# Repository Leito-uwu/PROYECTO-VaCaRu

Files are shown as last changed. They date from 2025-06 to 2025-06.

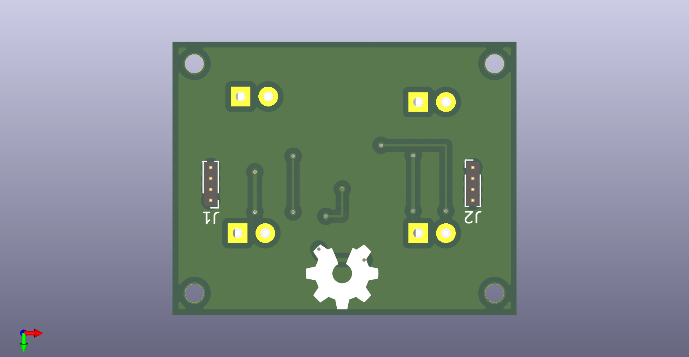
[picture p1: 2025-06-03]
01-PCB/Sensor de Color/PCBs/Sensor_TCS3200_volcado.png

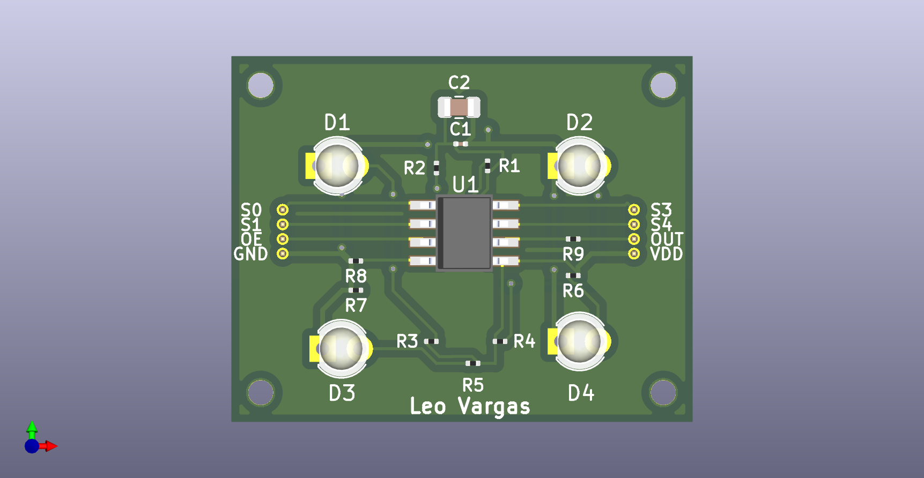
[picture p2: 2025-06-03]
01-PCB/Sensor de Color/PCBs/Sensor_TCS3200.png

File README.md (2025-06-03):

**PROTOTIPO DE SISTEMA DE CLASIFICACIÓN DE BOTELLAS DE VIDRIO AUTOMATIZADO POR COLOR**

**📝 Descripción del Proyecto**

Bienvenido a nuestro sistema de clasificación de botellas automatizado. Este proyecto está diseñado para optimizar y agilizar el proceso de separación de botellas según sus características, para esto estamos utilizando tecnología de electronica, mecánica y automatización.

Con este sistema, buscamos mejorar la eficiencia en la gestión de residuos, reducir costos operativos y promover prácticas más sostenibles en el reciclaje de envases. Nuestra solución integra sensores, procesamiento de diferenciacion de colores y algoritmos de clasificación para lograr una identificación rápida y precisa de los materiales.

¡Explora el repositorio y conoce más sobre cómo funciona este innovador sistema!

**🎯 Características Principales**

- 🔍 Clasificación Inteligente: Utiliza un sensor para identificar las caracteristicas de la botella.
- ⚡ Automatización Total: El sistema funciona de manera autónoma, reduciendo la necesidad de intervención humana.
- 🔄 Eficiencia en Procesamiento: Alta velocidad de detección y clasificación para optimizar la gestión de residuos.
- 🤖 Integración con Sensores: Emplea sensores para detectar el material y color de la botella
- 🌱 Enfoque en Sostenibilidad: Contribuye a la mejora del reciclaje y la reducción del impacto ambiental.
- 🛠️ Flexibilidad y Escalabilidad: Puede adaptarse a diferentes entornos y tipos de botellas.

**⚙️ Instalación y Configuración**

Reconfirgurable y programable, en el sentido que se puede tener acceso al codigo por ser un prototipo, y tomando en cuenta su configuracion de los sensores y actuadores. 

**🚀 Cómo Usarlo**
    Guía sobre la Funcionalidad:
    1) Colocar la botella en el comienzo de la cinta transportadora.
    2) Mediante el tablero de control, iniciar el proceso por la botonera.
    3) Detección del sensor de color e infrarrojo.
    4) Una vez detectado el brazo procede a la sujetación de la botella segun su color.
    5) Clasifica la botella en su respectivo deposito.
**🔎 Tecnologías Utilizadas**
ACTUADORES: 1 Mator Paso a Paso
            5 Servomotores
            1 Sensor FC-51
            1 Sensor TCS3200
            1 Pantalla LCD con I2C
            2 Pulsadores
            1 Driver ULN2003    
**👥 Contribución**
Autores: Alberto Ruiz
         Ramiro Caucota
         Leonardo Vargas

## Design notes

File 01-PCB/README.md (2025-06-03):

**PCB 👨‍💻**

Este apartado incluye los archivos necesarios para la fabricación y ensamblaje de la PCB del proyecto, como diseños en formato Gerber, esquemáticos, lista de materiales, archivos CAD y guías de ensamblaje de PCBs. Su objetivo es proporcionar toda la documentación requerida para replicar, modificar o mejorar el diseño original, asegurando una correcta integración del hardware con el sistema.

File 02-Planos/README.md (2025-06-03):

**PLANOS 🧑‍💻**
Este apartado contiene los planos técnicos y diagramas de la cinta transportadora, el brazo robótico y el depósito de separación, incluyendo diseños CAD, esquemáticos, lista de materiales e instrucciones de ensamblaje. Su objetivo es proporcionar la información necesaria para la fabricación y optimización de estos componentes, asegurando su correcta funcionalidad dentro del sistema.

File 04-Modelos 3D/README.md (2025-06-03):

Este apartado recopila los modelos tridimensionales de los componentes del proyecto junto con el análisis de fuerza aplicado a sus estructuras. 
Se incluyen archivos CAD detallados para impresión y ensamblaje, simulaciones que evalúan la distribución de esfuerzos y cargas en los materiales, especificaciones de los materiales utilizados y resultados de pruebas estructurales. Su objetivo es garantizar la viabilidad mecánica y optimizar el diseño, permitiendo detectar fallos, mejorar la resistencia y asegurar un desempeño óptimo en condiciones reales. Con esta información, se busca lograr un equilibrio entre eficiencia, durabilidad y seguridad en la construcción de cada elemento del sistema.

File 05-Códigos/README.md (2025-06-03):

**Codigo Fuente**
Este apartado contiene el código fuente del proyecto, estructurado en un esquema modular con carpetas separadas para maestro y esclavo. 
El código maestro gestiona la lógica central del sistema, tomando decisiones y enviando comandos a los módulos esclavos, mientras que el código esclavo ejecuta tareas específicas, como el control de motores, sensores y actuadores. Además, se incluyen protocolos de comunicación como UART, I2C para la interacción entre los dispositivos, junto con archivos de configuración para calibrar parámetros del sistema. Toda la documentación y comentarios en el código facilitan su comprensión, modificación y expansión, asegurando una implementación eficiente y adaptable a futuras mejoras.

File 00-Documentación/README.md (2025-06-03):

**DOCUMENTACIÓN 📝📓**

En este apartado se subieron la documentación  donde se explica las caracteristicas del proyecto ademas de los datasheet e informe final con todos los componentes necesarios para la comprension de la finalidad del prototipo.

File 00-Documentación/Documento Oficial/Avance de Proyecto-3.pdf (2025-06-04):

Prototipo de un Sistema Clasificador de Botellas de Vidrio en base a su color

José Ramiro Caucota

Carlos Alberto Ruiz Balderrama

Leonardo Vargas Condori

Docente: Kaleb Irahola Azad

Universidad Católica Boliviana San Pablo

Departamento de Ciencias de la Tecnología e Innovación

Carrera de Ingeniería Mecatrónica

Tarija

Prototipado Rápido

30 de mayo de 2025

Proto. De un Sis. Clasificador de botellas de vidrio en base a su color | i

TABLA DE CONTENIDO

Proto. De un Sis. Clasificador de botellas de vidrio en base a su color | ii

Proto. De un Sis. Clasificador de botellas de vidrio en base a su color | iii

LISTA DE TABLAS

Proto. De un Sis. Clasificador de botellas de vidrio en base a su color | iv

LISTA DE FIGURAS

Proto. De un Sis. Clasificador de botellas de vidrio en base a su color | v

Proto. De un Sis. Clasificador de botellas de vidrio en base a su color | vi

Proto. De un Sis. Clasificador de botellas de vidrio en base a su color | 1

RESUMEN

En Bolivia, muchas empresas de bebidas buscan reducir su impacto ambiental mediante la

reutilización de botellas de vidrio. Sin embargo, una de las principales dificultades radica en la

necesidad de separarlas por color antes de su reciclarlas. Actualmente, esta tarea se realiza de forma

manual, lo cual no solo ralentiza el proceso y resulta agotador para los trabajadores, también los

expone a riesgos por el contacto constante con el vidrio.

Ante esta problemática, el presente proyecto propone el desarrollo de un prototipo de

sistema clasificador de botellas de vidrio basado en su color, destinado a automatizar este proceso

y garantizar un manejo más seguro y eficiente. El sistema se fundamenta en sensores RGB e

Infrarrojo para identificar los colores principales de las botellas y en un mecanismo automatizado

de separación controlado mediante microcontroladores. La metodología incluyó el diseño,

construcción y prueba del prototipo en un entorno controlado.

Además, el prototipo reduce los riesgos laborales y promueve una mayor sostenibilidad

ambiental al facilitar el reciclaje de vidrio.

Palabras clave — Clasificación automática, sostenibilidad ambiental, botellas de

vidrio, Seguridad laboral, Reciclaje.

Proto. De un Sis. Clasificador de botellas de vidrio en base a su color | 2
I. PERFIL DEL PROYECTO
A. Planteamiento del problema

En Bolivia, muchas empresas de bebidas están trabajando para cuidar el medio ambiente, y

una de sus tareas más importantes es reutilizar botellas de vidrio. Pero para poder reutilizarlas

correctamente, primero hay que separarlas por color. El problema es que esto todavía se hace a

mano, con personas que pasan horas separando botellas una por una. Este trabajo no solo es lento

y cansador, sino que también puede ser peligroso, porque los trabajadores están en contacto

constante con vidrio.

Además, el método manual de clasificación presenta una alta probabilidad de errores, lo

cual repercute negativamente en la eficiencia de producción, incrementa los costos operativos y

provoca retrasos en la cadena de reciclaje. A pesar de que existen soluciones tecnológicas en otros

países, estas no resultan aplicables en el contexto boliviano debido a su elevado costo, complejidad

técnica y requerimientos de infraestructura industrial avanzada.

Por esta razón, se presenta una gran oportunidad de innovación: el desarrollo de un sistema

automatizado de clasificación de botellas por color, diseñado específicamente para el entorno

industrial nacional. Este sistema no solo optimizaría el proceso, reduciendo los errores, sino que

también mejoraría la seguridad de los trabajadores y contribuiría a la modernización de las líneas

de producción en el país.

B. Definición del problema

La clasificación manual de botellas de vidrio por color en la industria boliviana es un

proceso ineficiente, propenso a errores y riesgoso para los trabajadores. Aunque existen tecnologías

automatizadas en el mercado internacional, estas no se adaptan al contexto nacional por su alto

costo y complejidad operativa. Por tanto, se requiere una solución prototípica, automatizada y de

bajo costo, capaz de realizar esta tarea de forma segura y eficiente dentro de las limitaciones

técnicas y económicas del entorno local.

C. Objetivos
1) Objetivo General

Desarrollar un prototipo de un sistema automatizado de clasificación de botellas de vidrio

que reduzca el tiempo de clasificación respecto al proceso manual, utilizando materiales de bajo

costo, en un plazo de un mes y medio.

Proto. De un Sis. Clasificador de botellas de vidrio en base a su color | 3
2) Objetivos Específicos
- Gestionar el equipo de trabajo del proyecto con la asignación clara de roles, tareas

y herramientas de comunicación con técnicas de organización en un plazo de 2

semanas.

- Prototipar el sistema automatizado de clasificación de botellas de vidrio en un plazo

de 3 semanas, supervisando la eficiencia en el ensamblaje y asegurando un flujo de

trabajo óptimo durante todo el proceso de desarrollo.

- Evaluar el funcionamiento del prototipo en una semana, garantizando el

cumplimiento de los estándares de calidad establecidos, realizando los ajustes

necesarios para optimizar su rendimiento.

- Evaluar el rendimiento del prototipo en un plazo de una semana, con la finalidad de

verificar el cumplimiento de los estándares de calidad definidos y efectuar las

correcciones necesarias para optimizar su funcionamiento.

Delimitación

3) Límites

El presente proyecto está enfocado en el desarrollo de un prototipo funcional a escala

reducida para la clasificación automatizada de botellas de vidrio según su color. Debido a su

naturaleza académica y de prototipado rápido, se establecen las siguientes limitaciones:

- Escala reducida: No se emplearán botellas reales de vidrio. En su lugar, se utilizarán

objetos simulados fabricados en PLA u otros materiales ligeros, con dimensiones

similares a las botellas reales.

- Clasificación únicamente por color: El sistema estará diseñado exclusivamente para

diferenciar botellas según su color. No se incluirá reconocimiento de forma, tamaño,

volumen ni etiqueta.

- Componentes no industriales: Se utilizarán sensores y actuadores de bajo costo,

adecuados para demostraciones y validaciones funcionales, pero no aptos para

ambientes industriales exigentes o de alta precisión.

- Ambiente controlado: Las pruebas del sistema se realizarán en condiciones estables de

iluminación y temperatura. No se contempla el uso del prototipo en entornos con

humedad, polvo u otras variables ambientales que afecten la operación.

Proto. De un Sis. Clasificador de botellas de vidrio en base a su color | 4
4) Alcances

El alcance del proyecto contempla la diseño, construcción y validación funcional de un

sistema automatizado capaz de clasificar objetos simulados de acuerdo con su color. En este

contexto, el sistema incluirá:

- Una cinta transportadora funcional, equipada con sensores de presencia que detecten

la llegada de objetos a la zona de clasificación.

- Un sensor cromático que identifique los colores de los objetos en movimiento.
- Un brazo robótico controlado por servomotores, encargado de mover los objetos

clasificados hacia las zonas correspondientes.

- Un sistema de control embebido, basado en microcontroladores ESP32, que integre

y coordine todos los componentes del sistema.

- Una interfaz de visualización básica (pantalla LCD), para mostrar información del

estado del sistema.

Este prototipo demostrará la viabilidad técnica del proceso de clasificación automática por

color, estableciendo una base sólida para su futura adaptación a entornos industriales reales

mediante mejoras en sensores, materiales y robustez del sistema.

Proto. De un Sis. Clasificador de botellas de vidrio en base a su color | 5
II. | FUNDAMENTOS TEÓRICOS
A. Antecedentes

Se presenta el desarrollo de una estación automática de clasificación de productos basada en visión

de máquina, integrando software de código abierto y hardware comercial Allen Bradley. El

proyecto, realizado en la Universidad del Cauca, aborda el diseño mecánico median [1]te CAD

Solid Edge, la programación de visión artificial usando OpenCV en C++, y la automatización

siguiendo normas ISA. El sistema clasifica botellas plásticas y accesorios de PVC en cuatro tipos

establecidos, alcanzando una capacidad de hasta 224 botellas o 206 piezas de PVC por minuto con

un bajo margen de error del 0.8%. Se destaca la implementación de un enfoque modular y el uso

de redes industriales como DeviceNet para la comunicación entre componentes, logrando un

prototipo funcional que demuestra la viabilidad de integrar tecnologías libres y comerciales en

aplicaciones de automatización industrial. [1]

Este trabajo implementa un sistema de clasificación de botellas PET por color, utilizando visión

artificial con algoritmos de reconocimiento integrados en LabVIEW, y un sistema de control

basado en Arduino. El proceso se apoya en el algoritmo K-Nearest Neighbors (KNN) para

categorizar colores captados por una cámara, logrando una eficiencia del 75%. Se utilizó un módulo

de control neumático para realizar la separación física. Este tipo de solución se basa en técnicas de

aprendizaje supervisado y procesamiento de imágenes, fundamentales en la automatización del

reciclaje. El uso de interfaces entre software industrial y hardware embebido refuerza la viabilidad

en sistemas mecatrónicos autónomos. [2]

Se diseñó un sistema modular de banda transportadora fabricado mediante impresión 3D (material

PLA), enfocado a la emulación de procesos industriales. El proyecto se fundamenta en el uso de

sistemas de control abiertos (como Arduino), aplicando la metodología “Design Thinking” para

validar el desarrollo iterativo del prototipo. Su construcción sin tornillería permite ensamblajes

rápidos y bajos costos, y fomenta la educación técnica en el contexto de Industria 4.0. Este tipo de

prototipos representa una base didáctica y experimental ideal para pruebas de automatización,

sensores y clasificadores en procesos reales, además de ser escalables hacia aplicaciones en IoT o

monitoreo remoto. [3]

Proto. De un Sis. Clasificador de botellas de vidrio en base a su color | 6

En respuesta al aumento de residuos sólidos urbanos en Cochabamba, se diseñó un sistema

automatizado de clasificación mediante cinta transportadora y sensores. Basado en un controlador

lógico programable (PLC), el sistema identifica materiales reciclables por peso y tamaño,

dirigiéndolos a distintas áreas. Este enfoque se fundamenta en la lógica secuencial programable,

aplicada comúnmente en la industria para tareas de sorting. Al emplear sensores de proximidad,

fotointerrupción y carga, se mejora la eficiencia de clasificación y se reducen los costos operativos

y de separación manual. El sistema puede adaptarse a líneas de reciclaje urbano, mejorando la

sostenibilidad del modelo de gestión de residuos. [4]

En conclusión el desarrollo de un prototipo de sistema automatizado para la clasificación y

envasado de piezas metálicas, diseñado para optimizar los procesos industriales mediante el uso de

tecnologías neumáticas y controladores lógicos programables (PLC) con software TIA Portal V14.

El sistema incorpora cilindros neumáticos, electroválvulas, sensores magnéticos y transportadores

automatizados, permitiendo el empaquetado eficiente y seguro de productos metálicos. Entre sus

principales beneficios se destacan la reducción de costos de mano de obra, el incremento en la

seguridad de los operarios, la disminución de los tiempos de procesamiento y el aumento en la

productividad general. Este prototipo demuestra la viabilidad de la automatización como

herramienta clave para mejorar la eficiencia y la competitividad en sectores industriales como la

manufactura, automotriz, alimentario, entre otros. [5]

Proto. De un Sis. Clasificador de botellas de vidrio en base a su color | 7
III. | DISEÑO CONCEPTUAL
A. Boceto.

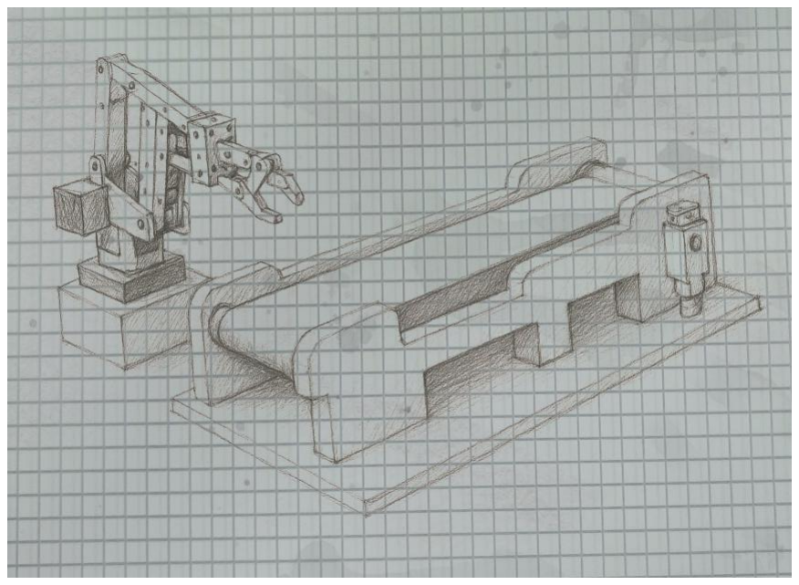
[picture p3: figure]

Figura 1 Boceto Inicial
B. Identificación de Requerimientos.

La encuesta realizada tuvo un alcance de 16 respuestas, donde los encuestados respondieron

a un total de 14 preguntas diseñadas específicamente para conocer la percepción del público

respecto al proyecto que se planea desarrollar. El objetivo principal de esta recolección de datos es

analizar las opiniones y expectativas de los usuarios potenciales, permitiendo identificar áreas de

mejora y ajustar el diseño del proyecto para asegurar su viabilidad y aceptación en el mercado.

Encuesta:

- Pregunta 1: El desarrollo del sistema representa una solución tecnológica

adecuada para el contexto local

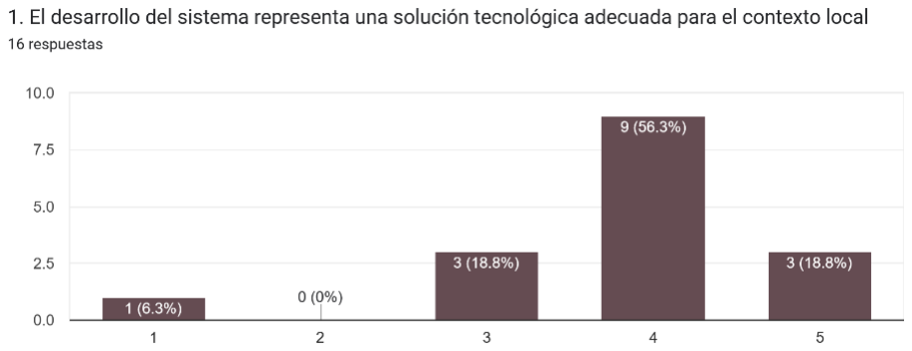
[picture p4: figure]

Figura 2 Análisis de la Pregunta 1

Proto. De un Sis. Clasificador de botellas de vidrio en base a su color | 8

El 75.1% de los encuestados considera que el sistema propuesto representa una solución

adecuada para el contexto boliviano. Esto valida la necesidad de una alternativa local, adaptada a

las limitaciones económicas y técnicas de la industria nacional.

- Pregunta 4: Que tan necesario ve que el sistema se adapte a diferentes entornos

como ser cambios en las condiciones de iluminación o humedad

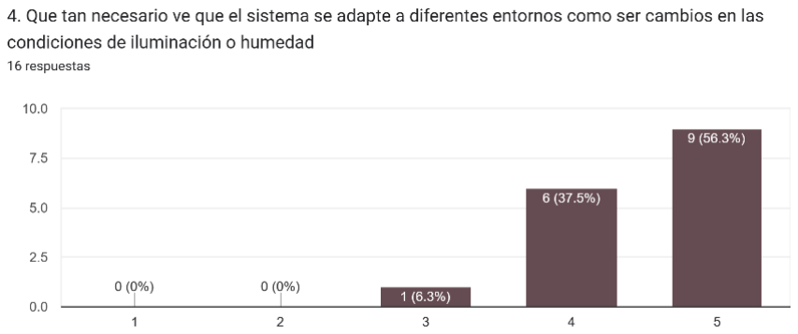
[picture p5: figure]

Figura 3 Análisis de la Pregunta 4 El 56.3% opina que el sistema debe adaptarse a condiciones variables como iluminación o

humedad. Esto plantea el requerimiento de implementar mecanismos que aseguren la robustez del

sistema ante cambios ambientales moderados.

- Pregunta 5: El prototipo debería ser fácil de operar por cualquier persona con

conocimiento básicos

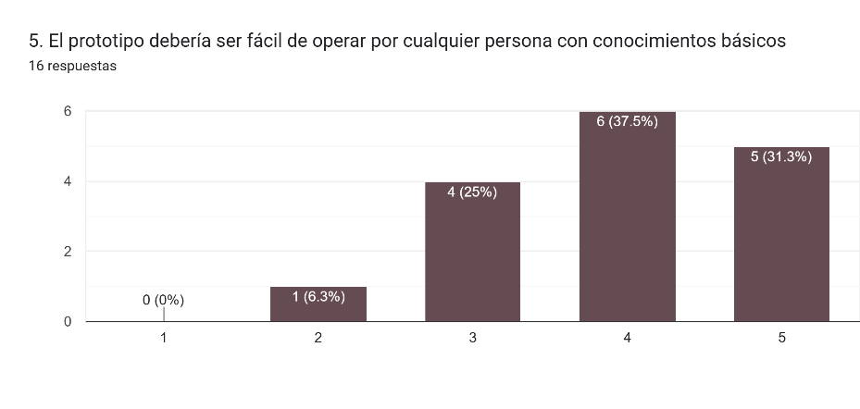
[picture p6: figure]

Figura 4 Análisis de la Pregunta 5 Donde los datos obtenidos nos muestran que un 68.8% nos indica que el prototipo del

sistema debe ser de fácil operación para las personas encargadas de manipular esta máquina, y un

25% se mantiene neutro y el 6.3% no lo ve necesario.

- Pregunta 7: EL proyecto tiene potencial para escalarse y adaptarse a distintas

necesidades de la industrial

Proto. De un Sis. Clasificador de botellas de vidrio en base a su color | 9

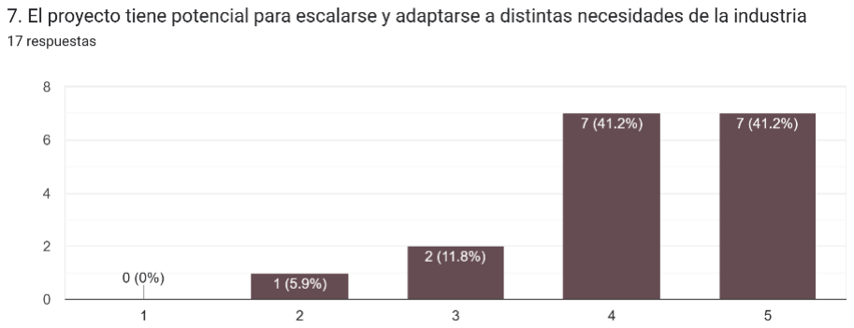
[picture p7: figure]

Figura 5 Análisis de la pregunta 7 Un 82.2% cree que el sistema puede escalarse y adaptarse a otros procesos industriales.

Esta percepción refuerza la necesidad de diseñar una arquitectura modular y flexible, con

posibilidad de integrar nuevas funciones o adaptarse a distintos flujos de trabajo, y solo un 11,8%

se mantiene neutral y el 5.9% no está de acuerdo.

- Pregunta 12: Está de acuerdo con que la automatización permitirá un flujo de

trabajo más continuo y sin interrupciones, lo que mejoraría la productividad en la

planta de reciclaje

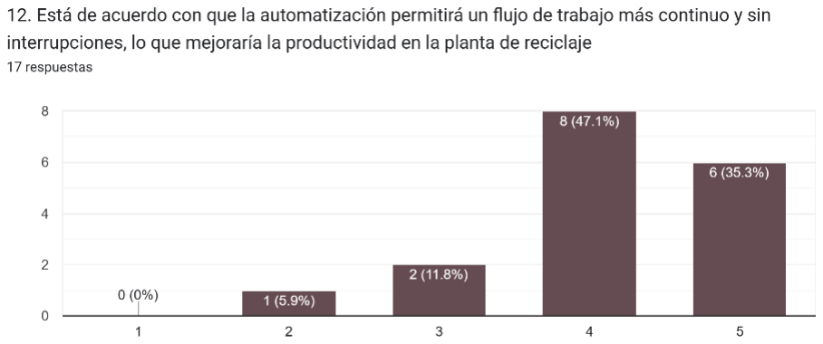
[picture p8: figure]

Figura 6 Análisis de la pregunta 12 El 82.4% considera que la automatización mejorará el flujo de trabajo en plantas

recicladoras, evidenciando el interés en reducir tiempos muertos, aumentar la eficiencia operativa

y minimizar el error humano. Y solo un 11.8% se mantiene neutro y un 5.9% no piensa está de

acuerdo.

- Pregunta 14: Considera que las empresas del sector del reciclaje de vidrio deberían

invertir en tecnologías automatizadas a pesar de los costos iniciales

Proto. De un Sis. Clasificador de botellas de vidrio en base a su color | 10

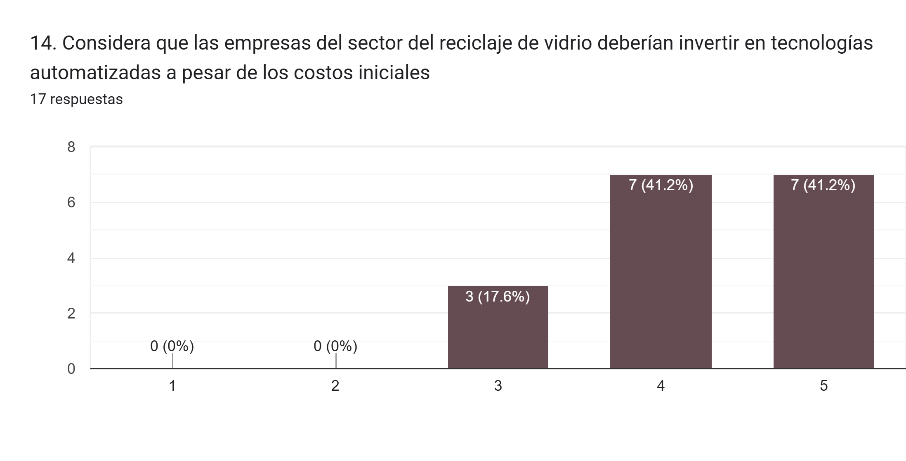
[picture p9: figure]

Figura 7 Análisis de la pregunta 14 También el 82.4% opina que las empresas del rubro deberían invertir en automatización,

incluso con un alto costo inicial, lo que sugiere que existe una disposición a adoptar nuevas

tecnologías si estas ofrecen beneficios sostenibles, luego de ello un 17.6% se mantiene neutral

respecto a esta pregunta.

C. Definición de funcionalidades.

Debe tener:

- Reconocer los colores de manera correcta: La precisión en la identificación

de colores es crucial para la correcta clasificación de las botellas.

- Sistema intuitivo para su manejo: Un sistema fácil de usar reduce el tiempo

de capacitación y minimiza errores operativos.

- Interfaz para monitoreo: La capacidad de monitorear el sistema en tiempo real

de manera remota permite detectar y corregir problemas rápidamente.

- Clasificación automática según aplicaciones específicas: La automatización

de la clasificación asegura que el proceso sea rápido y preciso.

- Materiales óptimos para el prototipo: Utilizar materiales de alta calidad

garantiza la durabilidad y fiabilidad del sistema.

- Sensores infrarrojos y ópticos: Estos sensores son esenciales para la detección

precisa de las botellas y su color.
- Área segura de trabajo para el operario: La seguridad del operario es

primordial para prevenir accidentes.

Debería tener:

Proto. De un Sis. Clasificador de botellas de vidrio en base a su color | 11
- Integrable a un proceso previamente automatizado: La capacidad de integrar

el sistema con procesos existentes facilita la implementación.

- Brazo robótico con alta precisión de movimiento: La precisión en el

movimiento del brazo robótico es crucial para la correcta manipulación de las

botellas.

- Flujo de trabajo continuo: Un flujo de trabajo sin interrupciones maximiza la

productividad.

Podría tener:

- Almacenamiento para Estadísticas. - El almacenamiento diseñado para

estadísticas implica la creación de una infraestructura que recopile, organice y

almacene grandes volúmenes de datos, permitiendo su posterior análisis.

- Aplicación Móvil para Monitero de Sistema. - Una aplicación móvil para

monitoreo de sistema permite la supervisión en tiempo real del rendimiento y

estado de un sistema o infraestructura tecnológica desde dispositivos portátiles.

- Sistema de Autodiagnóstico para Localizar Fallos. - Un sistema de

autodiagnóstico automatiza la detección y análisis de fallos dentro de una

infraestructura tecnológica o máquina. Utiliza algoritmos avanzados, como

redes neuronales o modelos de aprendizaje supervisado, para identificar

patrones de error.

- Conexión a Internet e Implementación de la Inteligencia Artificial. - La

conexión a Internet es fundamental para implementar inteligencia artificial, ya

que permite el acceso a grandes volúmenes de datos, el uso de procesamiento en

la nube y la actualización de modelos en tiempo real.

- Clasificación de más de 3 colores. - Sera esencial para la clasificación, de

objetos, tomado en cuenta rasgos de los colores principales que son: Azul, rojo

y verde, para este proceso de toma en cuenta la reflexión de luz, que nos

permitirá tener una mejor precisión al momento de aplicar el sensor.

No debe tener:

- Materiales de baja gama: Ya que no ofrecen la resistencia ni la durabilidad

necesarias para procesos de operación a largo plazo. Ocasionan fallas

Proto. De un Sis. Clasificador de botellas de vidrio en base a su color | 12

prematuras, incrementando los costos de mantenimiento y disminuyendo la

confiabilidad.

- Detección de formas o tamaños: Ya que en el proceso de reciclaje el criterio

principal de clasificación es el color de las botellas, por lo que agregar esta

funcionalidad solo aumentaría la complejidad y el costo del sistema sin aportar

un beneficio real.

- Autonomía energética: El sistema no debe operar con baterías recargables, ya

que está pensado para instalaciones industriales o semi-industriales donde se

cuenta con suministro eléctrico constante desde la red.

- Mal diseño y falta de calidad en la arquitectura: El diseño de la máquina

evitará estructuras débiles o mal ensambladas que comprometan su estabilidad.

- Fallos técnicos de manera recurrente: Minimizará fallos optimizando su

programación y asegurando una calibración precisa. Se descartarán

componentes poco fiables y se implementarán diagnósticos preventivos.

IV. DISEÑO DE INGENIERÍA

A. Selección

Para la selección de todos los puntos que requiere el proyecto se optó por el Método de

Ponderación de Criterios, donde se compararon 3 productos o métodos diferentes, de los cuales se

evaluó algunos criterios importantes para el grupo, donde se dio su respectiva ponderación, donde

se el ganador es que el obtiene el mejor puntaje.

1) Tecnologías

CRITERIO

### PONDERACIÓ

N

PRODUCTO A

PRODUCTO B
PRODUCTO C
FACILIDAD | 3 | 3 | 9 | 5 | 15 | 2 | 6
ENTORNO DE DESARROLLO | 2 | 2 | 4 | 3 | 6 | 5 | 10
COMPATABILIDAD | 4 | 2 | 8 | 5 | 20 | 3 | 12
DOCUMENTACIÓN | 1 | 3 | 3 | 4 | 4 | 3 | 3

Proto. De un Sis. Clasificador de botellas de vidrio en base a su color | 13
TOTAL | 10 | 24 | 45 | 31
Tabla 1 Tabla de decisión de Entorno de Programación En la matriz de decisión se tomaron muchos datos en cuenta como ser la facilidad de uso,

y la compatibilidad que este tiene con algunos componentes, donde son las ponderaciones más altas

y dándoles los valores necesarios se llegó a un ganador que es el Ard uino IDE con 45 puntos.

2) ComponentesCRITERIO

### PONDERACIÓ

N

PRODUCTO A

PRODUCTO B
PRODUCTO C
CONECTIVIDAD | 4 | 5 | 20 | 3 | 12 | 1 | 4
PROCESAMIENTO | 3 | 5 | 15 | 4 | 12 | 2 | 6
USO | 2 | 3 | 6 | 2 | 4 | 5 | 10
COSTOS | 1 | 4 | 4 | 3 | 3 | 4 | 4
TOTAL | 10 | | 45 | | 31 | | 24

Tabla 2 Matriz de decisión de los Microcontroladores En este apartado se comparó los microcontroladores que se usaran en el proyecto, donde

los criterios que se ponderaron con un mayor puntaje fueron los de la conectividad que estos tienen

con los diferentes componentes como ser sensores o actuadores, de igual manera su procesamiento

Proto. De un Sis. Clasificador de botellas de vidrio en base a su color | 14

que tan rápidos y eficientes son. Donde el ganador en este caso fue la ESP32 con 45 puntos seguido

de la STM32.

CRITERIO

### PONDERACIÓ

N

PRODUCTO A

PRODUCTO B
PRODUCTO C
USO | 3 | 5 | 15 | 4 | 12 | 2 | 6
COMPATIBILIDAD | 2 | 5 | 10 | 4 | 8 | 3 | 6
PRECISION | 3 | 3 | 9 | 4 | 12 | 5 | 15
COSTO | 2 | 5 | 10 | 4 | 8 | 2 | 4
TOTAL | 10 | | 44 | | 40 | | 31
Tabla 3 Matriz de decisión del Sensor de color Se compararon tres productos diferentes, donde se vio algunos criterios como ser el uso y

la precisión, ya que son puntos importantes que se necesitan para un buen desarrollo del proyecto

y una alta fiabilidad de su desarrollo. Donde el ganador fue el TCS3200, con un puntaje de 44. CRITERIO | PONDERACIÓ

N

PRODUCTO A

PRODUCTO B
PRODUCTO C
USO | 3 | 5 | 15 | 4 | 12 | 3 | 9
COMPATIBILIDAD | 2 | 5 | 10 | 5 | 10 | 4 | 8
PRECISION | 3 | 4 | 12 | 3 | 9 | 5 | 15
COSTO | 2 | 5 | 10 | 4 | 8 | 2 | 4
TOTAL | 10 | | 47 | | 39 | | 36

Tabla 4 Tabla de decisión del Sensor de Presencia

Proto. De un Sis. Clasificador de botellas de vidrio en base a su color | 15

Se buscó muchos sensores de los cuales se puso 3 los cuales se encontraban en Bolivia,

donde los criterios de evaluación fueron el uso, compatibilidad, precisión y el costo. Donde al darle

su puntaje respectivo el ganador fue FC-51 un sensor infrarrojo. CRITERIO | PONDERACIÓ

N

PRODUCTO A

PRODUCTO B
PRODUCTO C
VISUALIZACION | 3 | 5 | 15 | 3 | 9 | 4 | 12
USO | 2 | 5 | 10 | 5 | 10 | 4 | 8
COMPATIBILIDAD | 2 | 5 | 10 | 5 | 10 | 5 | 10
COSTOS | 3 | 4 | 12 | 5 | 15 | 3 | 9
TOTAL | 10 | | 47 | | 44 | | 39

Tabla 5 Matriz decisión de la Pantalla En este apartado lo que se busco fue las diferentes pantallas disponibles en el mercado,

donde las ponderaciones que se tomaron en cuenta fueron la visualización, uso, compatibilidad y

costos donde el ganador fue una pantalla LCD de 20x4, este con una ponderación de 47 puntos,

seguido de una pantalla de LCD de 16x4 con 44.

Proto. De un Sis. Clasificador de botellas de vidrio en base a su color | 16 CRITERIO | PONDERACIÓ

N

PRODUCTO A
PRODUCTO B

PRODUCTO C

PRECISION | 4 | 3 | 12 | 5 | 20 | 4 | 16
TORQUE | 3 | 3 | 9 | 5 | 15 | 4 | 12
CONTROL | 2 | 2 | 4 | 3 | 6 | 5 | 10
COMPATIBILIDAD | 1 | 4 | 4 | 5 | 5 | 5 | 5
TOTAL | 10 | | 29 | | 46 | | 43

Tabla 6 Matriz de decisión de motor Según esta matriz se compararon diferentes tipos de motores los cuales nos podrían mejorar

el desarrollo del proyecto, donde los criterios que se evaluaron fueron el de precisión y torque los

cuales fueron uno de los más importantes. Donde el ganador entre todos fue un Motor Paso a Paso

donde ganó con 46 puntos. CRITERIO

### PONDERACIÓ

N

PRODUCTO A
PRODUCTO B

PRODUCTO C

PRECISION | 3 | 5 | 15 | 3 | 9 | 5 | 15
TORQUE | 3 | 2 | 6 | 5 | 15 | 4 | 12
TAMAÑO | 2 | 5 | 10 | 2 | 4 | 5 | 10
DURABILIDAD | 2 | 3 | 6 | 4 | 8 | 5 | 10
TOTAL | 10 | | 37 | | 36 | | 47

Proto. De un Sis. Clasificador de botellas de vidrio en base a su color | 17

Tabla 7 Matriz de decisión del Servomotor En este aparatado se vieron diferentes tipos de servomotores los cuales se usarán en el brazo

robótico, donde se busca de los motores a seleccionar es la precisión y el torque esto debido que se

requiere un correcto funcionamiento del brazo. Donde dándole las puntuaciones a cada elemento

se obtuvo que el ganador fue MG90S con 47 puntos.

3) Materiales CRITERIO

### PONDERACIÓ

N

PRODUCTO A
PRODUCTO B

PRODUCTO C

FLEXIBILIDAD | 2 | 2 | 4 | 2 | 4 | 6 | 12
RESISTENCIA | 4 | 3 | 12 | 4 | 16 | 4 | 16
MANIPULABLE | 1 | 4 | 4 | 2 | 2 | 2 | 2
COSTOS | 3 | 5 | 15 | 3 | 9 | 1 | 3
TOTAL | 10 | | 35 | | 31 | | 33
Tabla 8 Matriz de decisión del Material Para la construcción de todo el proyecto se tomó en cuenta los diferentes materiales con los

que se puede imprimir, donde al comparar estos 3 productos con sus respectivos criterios se obtuvo

que el ganador fue el PLA con una puntuación de 35 puntos.

Proto. De un Sis. Clasificador de botellas de vidrio en base a su color | 18
4) Modelos

CRITERIO

### PONDERACIÓ

N

PRODUCTO A
PRODUCTO B

PRODUCTO C

PRECISION | 3 | 5 | 15 | 3 | 9 | 4 | 12
EFICIENCIA | 1 | 5 | 5 | 4 | 4 | 3 | 3
COSTOS | 2 | 4 | 8 | 5 | 10 | 3 | 6
MANTENIMIENTO | 4 | 4 | 16 | 5 | 20 | 3 | 12
TOTAL | 10 | | 44 | | 43 | | 33
Tabla 9 Matriz de decisión de la Relación de Trasmisión Para el apartado mecánico se vieron muchas opciones de como implementar los diferentes tipos

de relaciones de transmisiones, donde al evaluarlas con los siguientes criterios como ser la

precisión, el mantenimiento que se le debe dar se pudo llegar a un ganador que fue una relación

por engranajes ganadora por 44 puntos seguida de la polea con banda.

B. Esquematización
1) Diagramas de Bloques
a) Nivel 0

Proto. De un Sis. Clasificador de botellas de vidrio en base a su color | 19

Figura 8 Nivel 0 del proyecto Este nivel muestra una vista general del sistema completo. Se identifican las entradas y

salidas principales conectadas al bloque central, de igual manera se ve los servicios que se

requiere para un correcto funcionamiento del proyecto. En la parte inferior se puede ver que el

proyecto contará con una pantalla con la pueda mostrar los datos necesarios al usuario.

Este nivel resume los componentes esenciales o más básico de todo el proyecto, por eso se

define como el Nivel 0.

b) Nivel 1

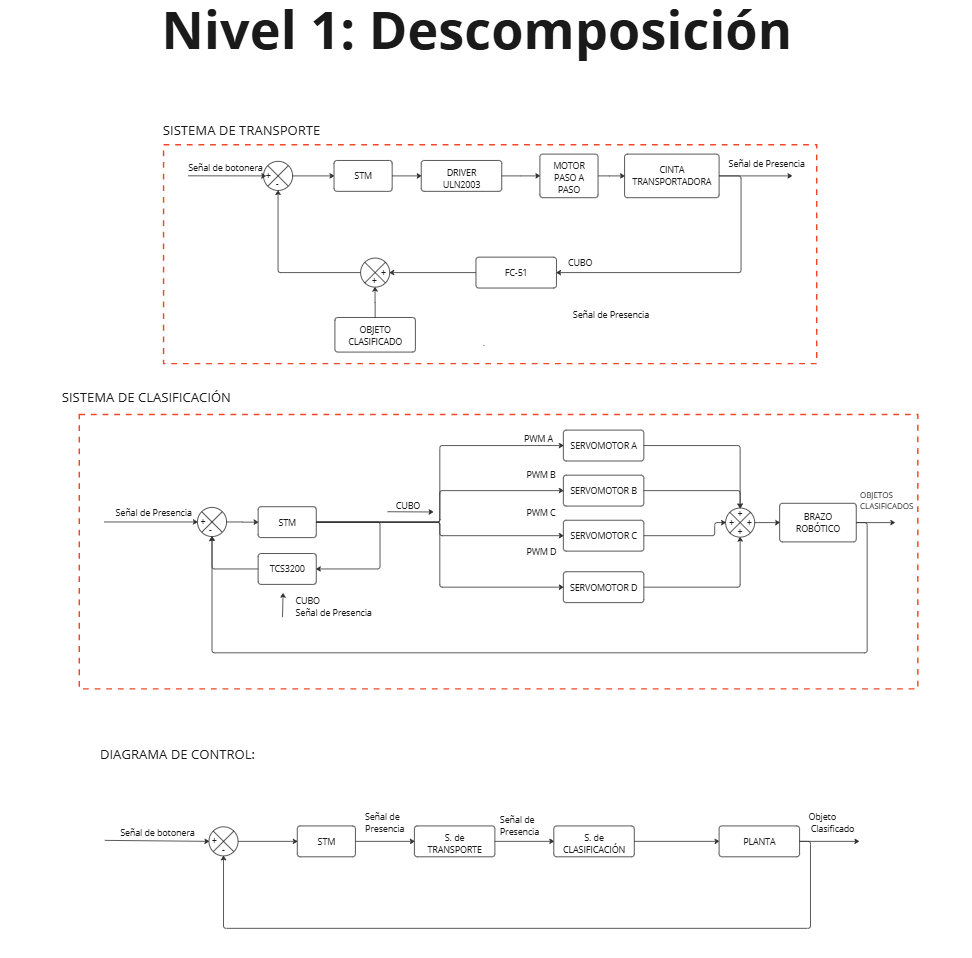
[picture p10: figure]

Figura 9 Nivel 1 del proyecto

Proto. De un Sis. Clasificador de botellas de vidrio en base a su color | 20

En este apartado se detalla cómo está construido el sistema, separándolo en tres

subsistemas, esto se hace para tener comprender de mejor manera como funciona todo el

proceso de manera genérica. Este nivel conocido como diagramas de bloques, nos muestra

cómo cada parte del sistema se comunica entre sí, siguiendo los diagramas presentes de

Control.

Como ser el subsistema de transporte el cual depende de diferentes tipos de bloques

los cuales son: el microcontrolador, que este le llega la señal de entrada la cual es comparada

con la señal retroalimentada, este toma una decisión y de eso pasa al controlador Driver

donde hace que nuestro bloque actuador que es el motor se prenda o apague, este

interactuando en nuestra planta que es la cinta transportadora, seguido de eso tenemos una

retroalimentación con nuestro sensor de FC-51, el cual debe mandar una señal al bloque

sumador, donde se debe sumar con la señal enviada por el siguiente subsistema.

En el siguiente diagrama se puede determinar como el subsistema de clasificación,

funciona con el mismo microcontrolador, el cual primero tiene una pequeña

retroalimentación con el sensor de color, el cual nos indica cual es el color del objeto. Con

esto nos manda la señal a los diferentes tipos de servomotores los cuales estarán presentes

en el brazo robótico, cada uno con un ángulo diferente, con la finalidad de llevar el objeto

a su debido lugar.

En el diagrama final se ve como ambos subsistemas están conectados en serie, donde

el microcontrolador es el encargado de mandar sus debidas órdenes a cada bloque de control

para tener una retroalimentación, viendo si el proceso se culminó.

Proto. De un Sis. Clasificador de botellas de vidrio en base a su color | 21
c) Nivel 2

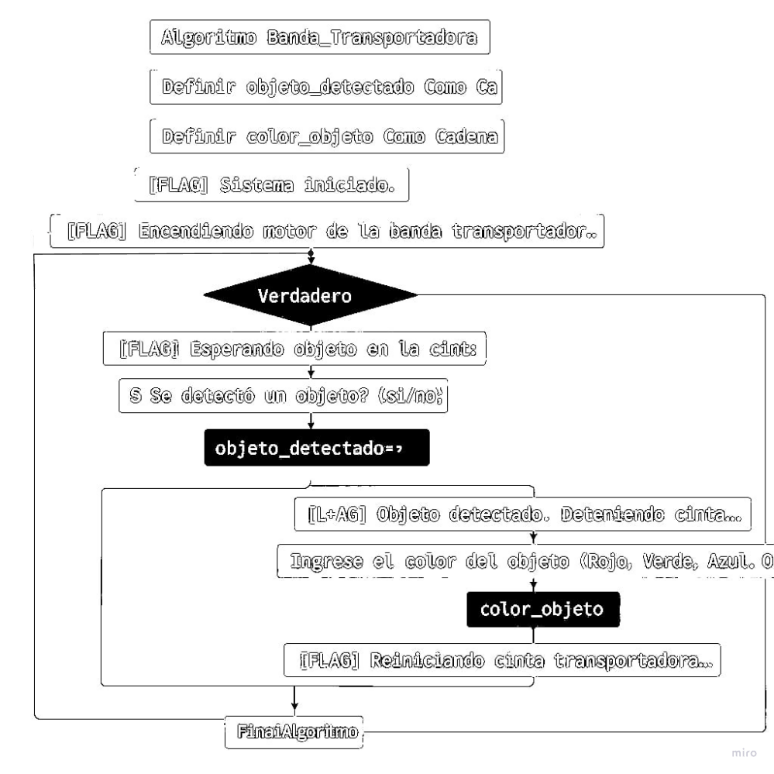
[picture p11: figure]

Figura 10 Nivel 2 de la Banda Transportadora El siguiente diagrama de flujo representa el comportamiento lógico del sistema de

clasificación por color mediante cinta transportadora. El algoritmo comienza con la activación del

motor, detecta la presencia de un objeto mediante sensor infrarrojo, y una vez detectado, se realiza

la lectura del color del objeto. Según el color identificado, el sistema procede a clasificarlo

mediante el movimiento del brazo robótico a la zona correspondiente. Finalmente, el ciclo se

reinicia.

Proto. De un Sis. Clasificador de botellas de vidrio en base a su color | 22

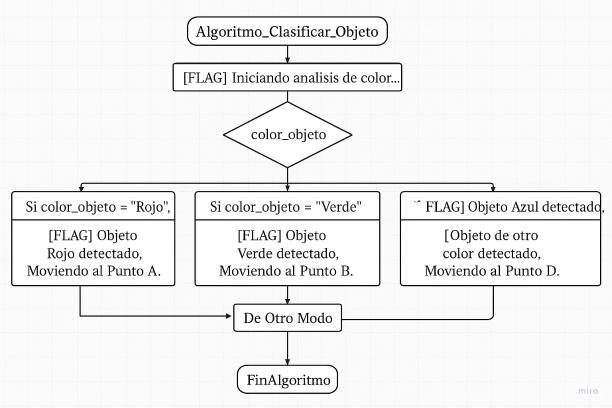
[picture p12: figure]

Figura 11 Nivel 2 del Brazo Robótico El diagrama de flujo “Algoritmo_Clasificar_Objeto” detalla la lógica interna del proceso

de clasificación según el color detectado por el sensor.

Una vez que se ha identificado un objeto y se ha leído su color, el sistema entra en esta

subrutina de decisión. Mediante una serie de condiciones, compara el valor color_objeto con los

colores programados y envía una señal al brazo robótico para mover el objeto a su posición de

destino correspondiente:

- Si el color es rojo, el objeto es enviado al Punto A.
- Si el color es verde, el objeto es enviado al Punto B.
- Si el color es azul u otro distinto, el objeto se redirige al Punto D como clasificación

general.

Proto. De un Sis. Clasificador de botellas de vidrio en base a su color | 23

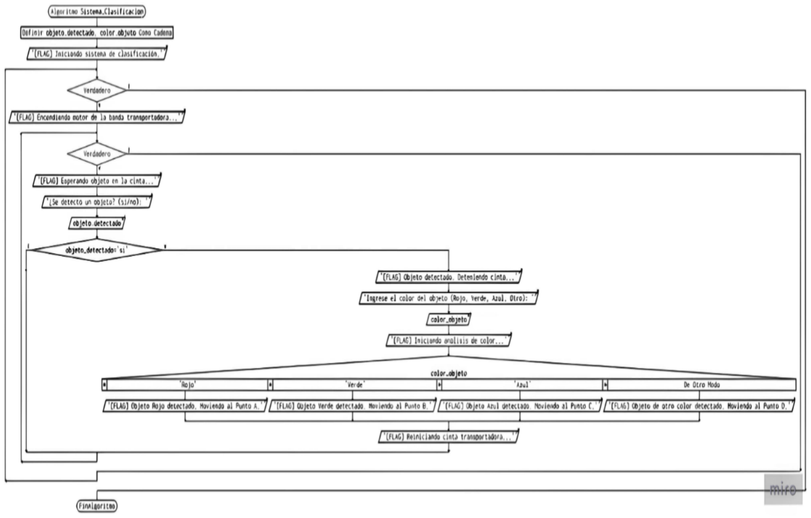
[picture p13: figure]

Figura 12 Nivel 2 de todo el proyecto El diagrama de flujo completo del sistema representa la lógica central de operación

del clasificador automático de botellas por color. Se comienza con la inicialización del

sistema, seguido del encendido del motor de la cinta transportadora. Cuando un sensor

infrarrojo detecta la presencia de un objeto, la cinta se detiene y se procede al análisis del

color utilizando un sensor cromático.

El sistema clasifica el objeto según su color, enviando señales al brazo robótico para

moverlo a un punto específico A, B, C o D. Finalmente, se reinicia la cinta y se repite el

proceso.

El Nivel 2 con diagramas de flujo muestra cómo piensa y actúa el sistema paso a paso,

dividiendo el proceso en transporte, detección, análisis de color y clasificación.

Este nivel es clave para programar el comportamiento del sistema en un microcontrolador

o software de automatización.

Proto. De un Sis. Clasificador de botellas de vidrio en base a su color | 24
d) DFP

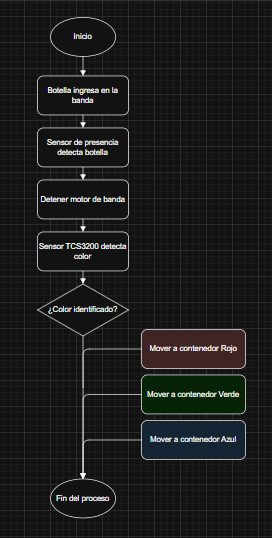
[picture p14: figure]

Figura 13 Diagrama de Flujo del Proyecto
e) Planos Mecánicos

Proto. De un Sis. Clasificador de botellas de vidrio en base a su color | 25

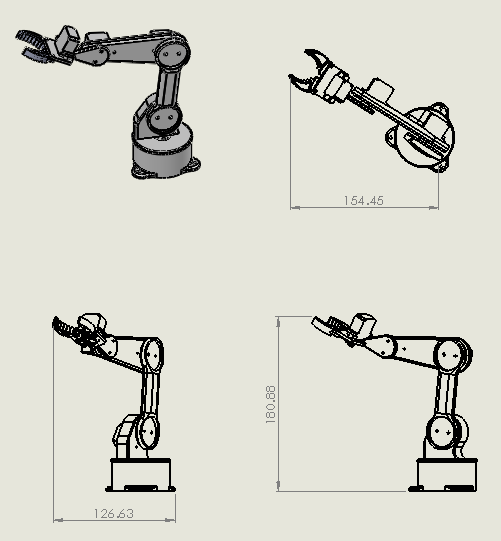
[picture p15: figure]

Figura 14 Plano Brazo Robótico

Proto. De un Sis. Clasificador de botellas de vidrio en base a su color | 26

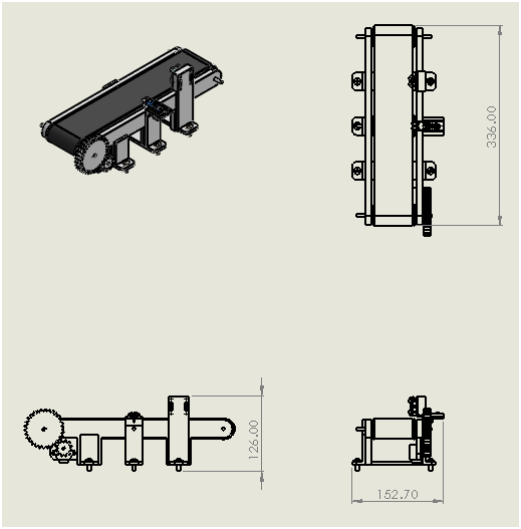
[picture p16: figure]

Figura 15 Plano Cinta Transportadora

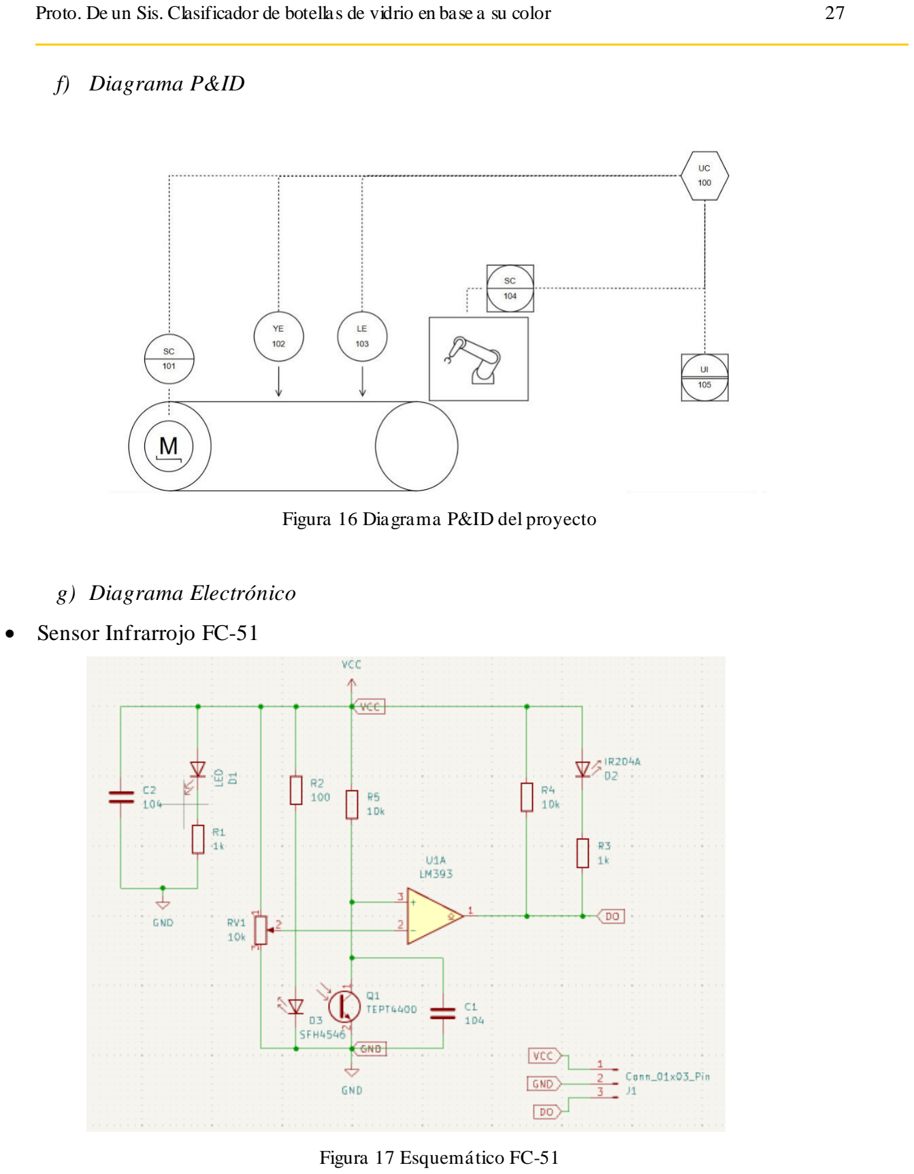
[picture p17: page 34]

Proto. De un Sis. Clasificador de botellas de vidrio en base a su color | 27
f) Diagrama P&ID

Figura 16 Diagrama P&ID del proyecto

g) Diagrama Electrónico
- Sensor Infrarrojo FC-51

Figura 17 Esquemático FC-51

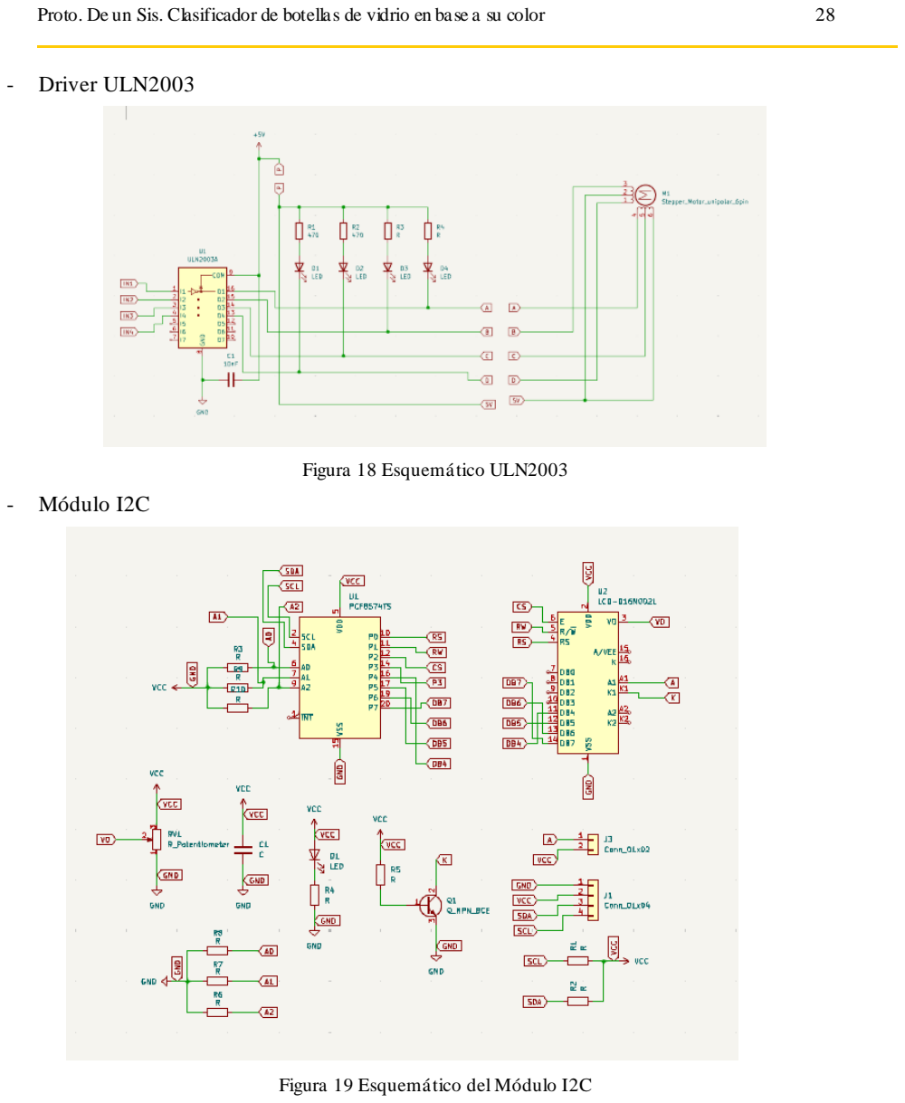
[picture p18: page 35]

Proto. De un Sis. Clasificador de botellas de vidrio en base a su color | 28
- Driver ULN2003

Figura 18 Esquemático ULN2003
- Módulo I2C

Figura 19 Esquemático del Módulo I2C

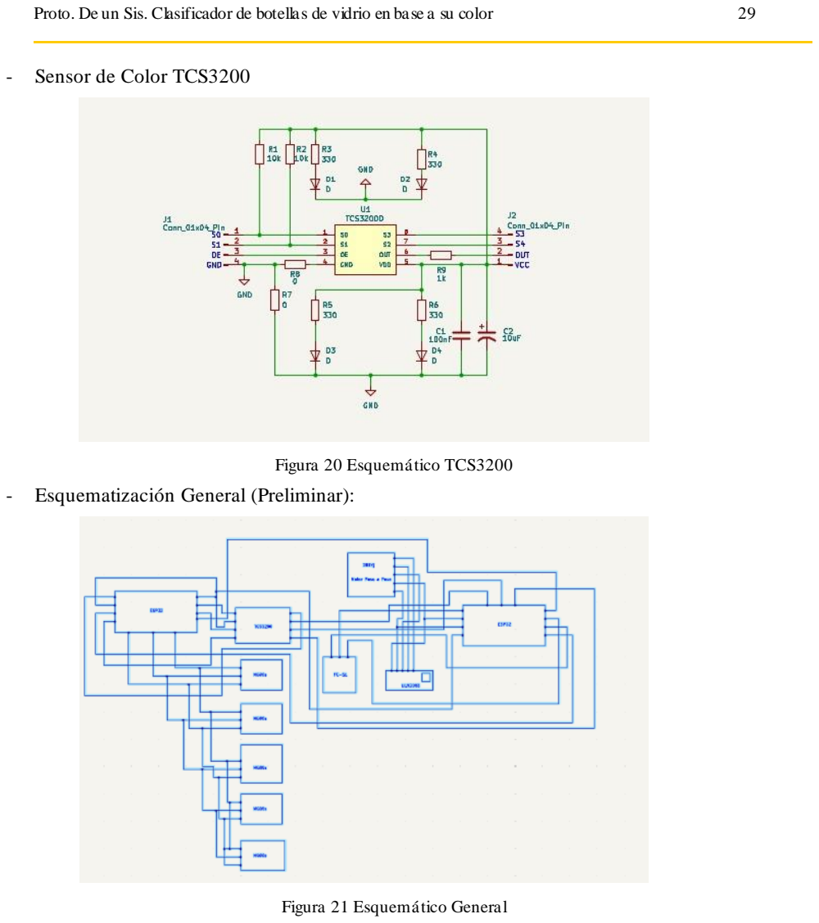
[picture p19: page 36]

Proto. De un Sis. Clasificador de botellas de vidrio en base a su color | 29
- Sensor de Color TCS3200

Figura 20 Esquemático TCS3200
- Esquematización General (Preliminar):

Figura 21 Esquemático General

Proto. De un Sis. Clasificador de botellas de vidrio en base a su color | 30
h) Diagrama PCB
- Sensor Infrarrojo FC-51

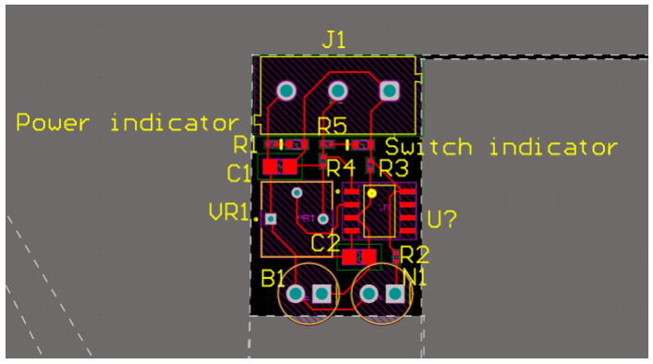
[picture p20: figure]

Figura 22 PCB FC-51
- Modulo ULN2003

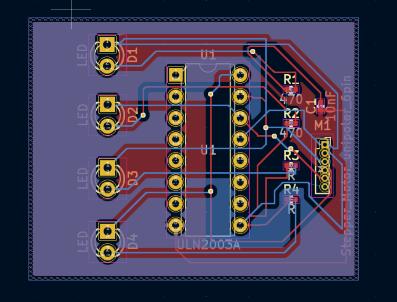
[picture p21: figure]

Figura 23 PCB ULN2003

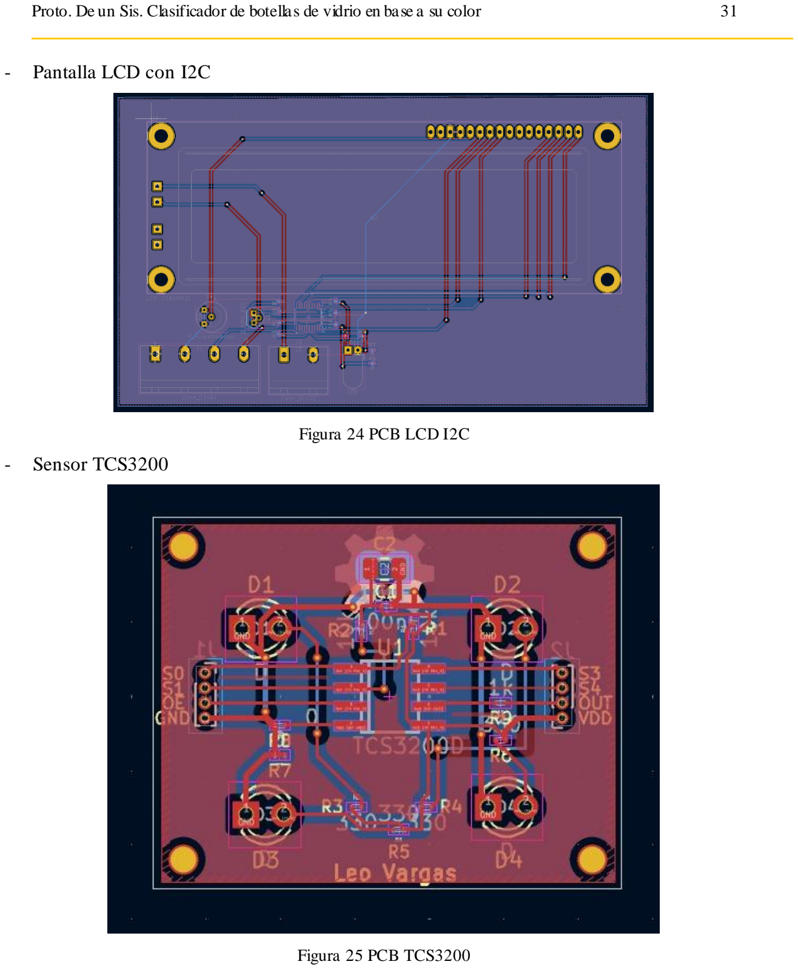
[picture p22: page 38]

Proto. De un Sis. Clasificador de botellas de vidrio en base a su color | 31
- Pantalla LCD con I2C

Figura 24 PCB LCD I2C
- Sensor TCS3200

Figura 25 PCB TCS3200

Proto. De un Sis. Clasificador de botellas de vidrio en base a su color | 32
C. Dimensionamiento
1) Estructural
a) Cálculos de Ejes

Proto. De un Sis. Clasificador de botellas de vidrio en base a su color | 33

En la parte del cálculo de fuerzas se sabe que las botellas impresas pesan alrededor de 7gr.

Donde al menos dos de ellas estarán presenten en la banda dando un peso de 14gr, sacando un

factor de estimación se busca llegó a un peso de 20gr y haciendo una conversión. Se pudo obtener

una fuerza de 0.14 N los cuales se encuentran distribuidos sobre todo el eje. Seguido de ello en las

parades de los mismos ejes se toma en cuenta el peso de estas mismas dándonos un aproximado de

0.04 N, en cada lado. Ingresando todos estos datos al MDSolid nos da los momentos flexores

máximos, donde se ingresará a la siguiente parte.

Proto. De un Sis. Clasificador de botellas de vidrio en base a su color | 34

Obtenido el Esfuerzo Normal mediante la fórmula dada, se llegó un factor de 0.509

KN/mm². Este dato se usa para saber nuestro factor de seguridad de todo el proyecto. Donde viendo

los límites a la fatiga, se llegó a un factor de seguridad de 2. Indicando que el eje si cuenta con las

especificaciones técnicas necesarias.

Proto. De un Sis. Clasificador de botellas de vidrio en base a su color | 35

En este apartado se buscó sacar el cálculo cinemático de los ejes. Donde se requiere de

varios datos los cuales ya se obtuvieron del análisis estático. Donde se puede ver que nuestro factor

de seguridad subió a 3. Indicando que el eje diseñado si cumple con los requisitos necesarios.

- Cálculos de Engranajes

Proto. De un Sis. Clasificador de botellas de vidrio en base a su color | 36

Se sabe que los engranajes tienen una relación de transmisión de acuerdo con el número

de dientes o los diámetros de las ruedas dentadas. Teniendo los dientes de 30 y 12, se llegó a una

relación de 2.5. En este caso lo que se plantea es reducir la velocidad del motor, para aumentar el

torque.

Proto. De un Sis. Clasificador de botellas de vidrio en base a su color | 37
b) Cálculos Estructurales
- Banda Transportadora
- Tensiones:

Figura 26 Análisis de tensiones
- Factor de Seguridad:

Figura 27 Análisis de Seguridad

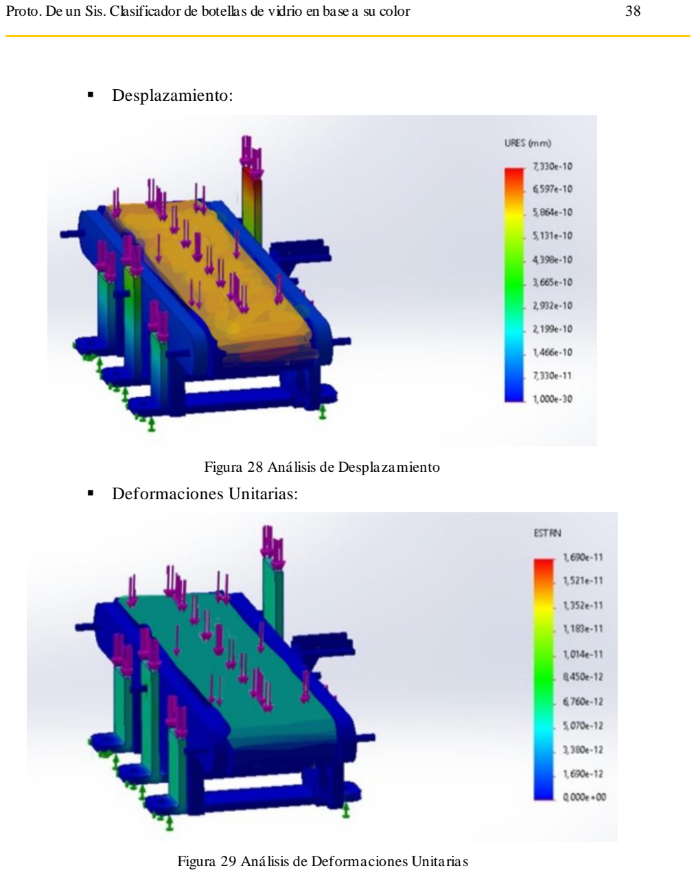
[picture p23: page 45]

Proto. De un Sis. Clasificador de botellas de vidrio en base a su color | 38
- Desplazamiento:

Figura 28 Análisis de Desplazamiento
- Deformaciones Unitarias:

Figura 29 Análisis de Deformaciones Unitarias

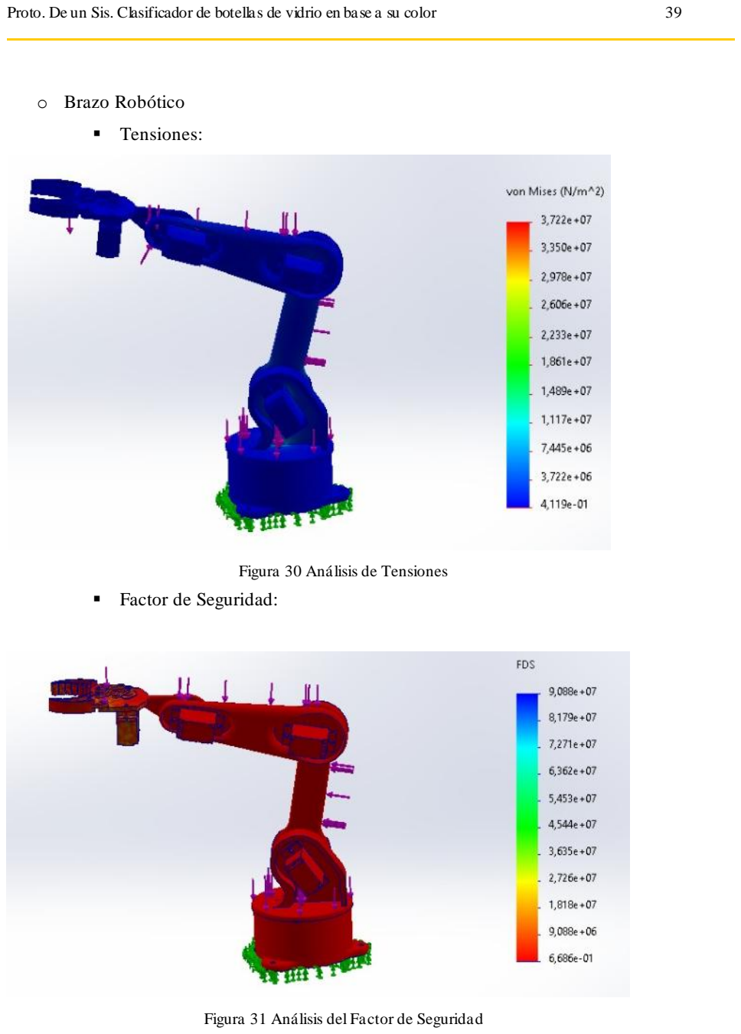
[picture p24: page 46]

Proto. De un Sis. Clasificador de botellas de vidrio en base a su color | 39
- Brazo Robótico
- Tensiones:

Figura 30 Análisis de Tensiones
- Factor de Seguridad:

Figura 31 Análisis del Factor de Seguridad

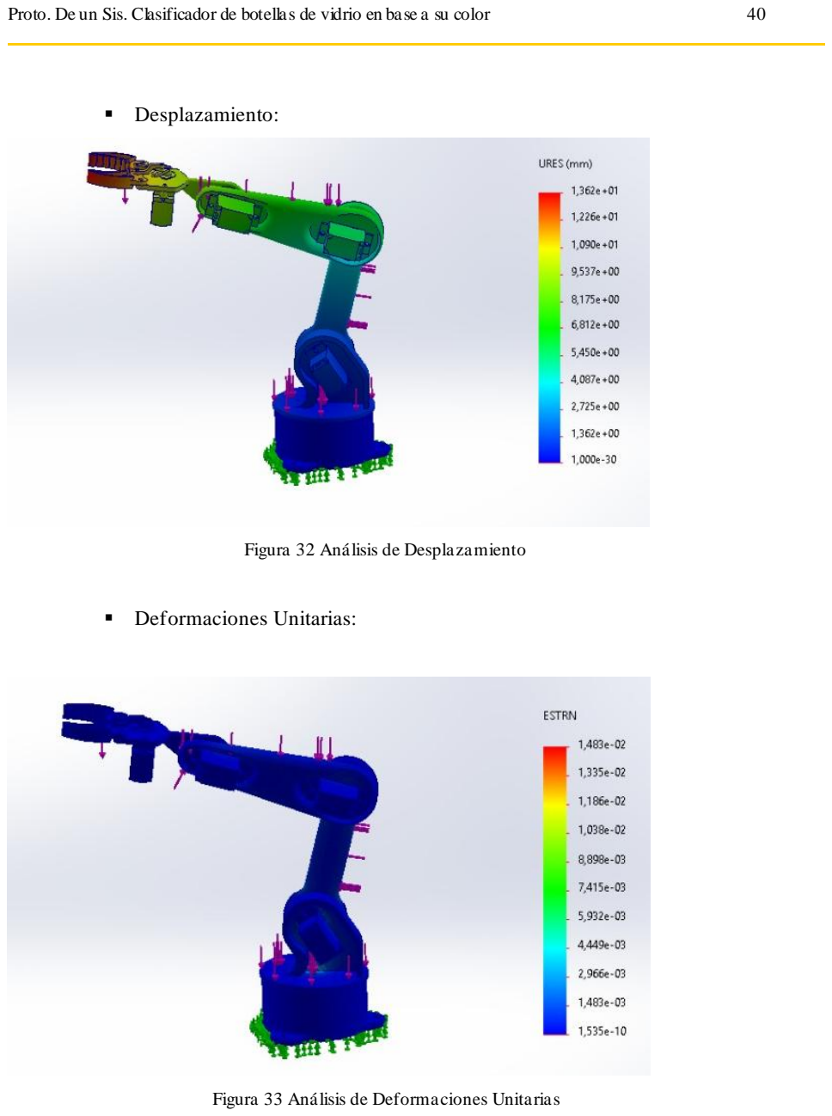
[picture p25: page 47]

Proto. De un Sis. Clasificador de botellas de vidrio en base a su color | 40
- Desplazamiento:

Figura 32 Análisis de Desplazamiento

- Deformaciones Unitarias:

Figura 33 Análisis de Deformaciones Unitarias

Proto. De un Sis. Clasificador de botellas de vidrio en base a su color | 41
2) Modelo Matemático del Brazo (Preliminar)

Proto. De un Sis. Clasificador de botellas de vidrio en base a su color | 42

Proto. De un Sis. Clasificador de botellas de vidrio en base a su color | 43

Como se mencionó al inicio, el código desarrollado en Google Colab corresponde a un

modelo preliminar del brazo robótico, el cual se encuentra en una etapa inicial de implementación.

Actualmente, se han definido las matrices de transformación homogénea para cada eslabón del

brazo, permitiendo construir tanto el modelo cinemático directo como el modelo cinemático

inverso.

Posteriormente, se aplicó la derivación correspondiente para obtener el modelo de

velocidades lineales y angulares, necesarias para el análisis dinámico futuro. Todo el desarrollo ha

sido estructurado mediante funciones reutilizables, de modo que, al ingre sar los parámetros

adecuados, se pueden obtener los resultados deseados de forma directa.

Este entorno de trabajo sienta las bases para futuras ampliaciones, como la integración de

modelos dinámicos completos, análisis de trayectorias y simulaciones más precisas del

comportamiento del sistema robótico.

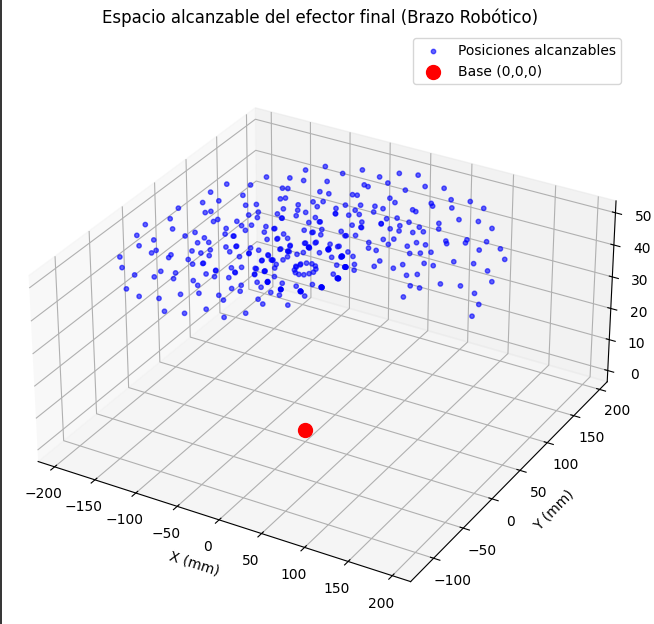
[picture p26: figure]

Figura 34 Posiciones Alcanzables del Brazo Robótico En esta gráfica se puede observar el espacio de trabajo del efector final del brazo robótico.

Debido a que el primer eslabón solo permite una rotación en un rango limitado de 0 a 180 grados,

el brazo no puede cubrir todo el entorno circular a su alrededor. Esta restricción reduce su alcance

efectivo a únicamente la mitad del área que podría cubrir si tuviera un movimiento completo de

360 grados.

Proto. De un Sis. Clasificador de botellas de vidrio en base a su color | 44

Esta limitación puede ser aceptable en aplicaciones donde el área de trabajo esté orientada

hacia un solo lado, pero debe considerarse si se desea escalar el sistema o utilizarlo en entornos

industriales más complejos.

3) Filtros

Cálculo del Filtro FIR

Un filtro FIR de orden 4 (5 coeficientes) de promedio móvil:

ℎ[k] =

1
5

, k = 0,1,2,3,4,5

Expresión general:

y[n] = ∑

1
5

∗ x[n − k]

4

k=0
Datos de Frecuencia:
- Rojo: 1200 Hz, 1220 Hz, 1195 Hz, 1210 Hz, 1205 Hz
- Verde: 1300 Hz, 1280 Hz, 1290 Hz, 1275 Hz, 1285 Hz
- Azul: 1400 Hz, 1410 Hz, 1395 Hz, 1405 Hz, 1400 Hz

Cálculo Manual:

Rojo Filtrado = 1200+1220+1195+1210+1205 5

= 1206[Hz]

Verde Filtrado = 1300+1280+1290+1275+1285 5

= 1286[Hz]

Azul Filtrado = 1400+1410+1395+1405+1400 5

= 1402[Hz]

Resultado Esperado:

- Rojo filtrado: 1206 Hz
- Verde filtrado: 1286 Hz
- Azul filtrado: 1402 Hz

Proto. De un Sis. Clasificador de botellas de vidrio en base a su color | 45
4) Prototipado

Proto. De un Sis. Clasificador de botellas de vidrio en base a su color | 46

Durante la etapa de prototipado del sistema, se utilizó impresión 3D mediante tecnología

FDM (Fabricación por Deposición Fundida), haciendo uso del software Ultimaker Cura como

entorno de configuración. Esta herramienta permitió ajustar los parámetros de impresión según las

necesidades del proyecto, priorizando la rapidez, funcionalidad y bajo consumo de recursos.

Se optó por una configuración predeterminada “Low Quality” la cual permite imprimir con

mucha más rapidez, esto resulta ideal para etapas de validación rápida. Aunque esta opción no

ofrece el mejor acabado visual, fue suficiente para piezas funcionales no estéticas, permitiendo

comprobar la geometría, el ensamblaje y la interacción entre componentes del sistema.
El material utilizado fue PLA (Ácido Poliláctico), seleccionado por su bajo costo, facilidad

de impresión y buena disponibilidad en el mercado local. Además, su rigidez es adecuada para

Proto. De un Sis. Clasificador de botellas de vidrio en base a su color | 47

prototipos que no están sometidos a esfuerzos intensos. También se valoró el hecho de que el PLA

es biodegradable, lo cual mantiene coherencia con el enfoque ambiental del proyecto.

Para las piezas que requerían soporte estructural, se eligieron soportes de tipo “árbol”, ya

que brindan estabilidad suficiente durante la impresión y, al mismo tiempo, son fáciles de remover,

reduciendo el tiempo de post-procesamiento y evitando daños en las superficies de las piezas.

También se ajustó un poco la temperatura de impresión, tanto del cabezal como de la base,

para adaptarse mejor al clima del lugar. Esto ayudó a que las piezas se pegaran bien desde el inicio

y no se deformaran mientras se imprimían.

5) Electrónico
- Cálculo de los Cables

Proto. De un Sis. Clasificador de botellas de vidrio en base a su color | 48

Para obtener los datos de los diámetros de los cables, se vio el consumo en potencia de

todos los componentes que se ubican en el proceso y con esto se obtuvo un cable con calibre de

26AWG y 22AWG.

6) PCB

Para el diseño y dimensionamiento de las pistas de la PCB se utilizaron herramientas CAD

como Altium Designer y KiCad, las cuales permitieron aplicar reglas de diseño “DRC” para definir

el ancho y separación de rutas según los requerimientos eléctricos del circuito. Se dimensionaron

las pistas considerando la corriente esperada en cada sección (alimentación, señal, tierra),

utilizando calculadoras basadas en el estándar IPC-2221. Se emplearon pistas más anchas para

líneas de alimentación y masa, y más delgadas para señales lógicas, garantizando así un diseño

seguro y funcional en una PCB de hasta dos capas.

Tabla 10 Datos estandarizados de la PCB

Proto. De un Sis. Clasificador de botellas de vidrio en base a su color | 49
7) Alimentación

### DIMENSIONAMIENTO DEL CONSUMO

Componentes | Voltaje de operación (V) | Consumo típico (mA) | Consumo máximo estimado (mA) | Cantidad | Consumo total (mA)
ESP32-S3 | 3.3 | 160 | 240 | 2 | 480
Servomotor MG90S | 4.8 – 6.0 | 200 | 300 | 5 | 1500
Motor paso a paso 28BYJ-48 | 5 | 240 | 300 | 1 | 300
Driver ULN2003 | 5 | 10 | 50 | 1 | 50
Sensor de color TCS3200 | 3.3 / 5.0 | 20 | 60 | 1 | 60
Sensor IR FC-51 | 3.3 / 5.0 | 10 | 20 | 1 | 20
TOTAL, ESTIMADO | - | - | - | - | 2410 mA (2.41 A)

Tabla 11 Cálculo de alimentación Según la tabla de estimación de consumo eléctrico, el prototipo tendrá un consumo máximo

aproximado de 2.41(A). Debido a esta demanda de corriente, no es viable alimentar el sistema

únicamente desde una fuente interna o del microcontrolador, ya que podría sobrecargarse.

Por esta razón, se requiere un sistema de alimentación externa que proporcione la energía

necesaria de forma estable y segura para todos los componentes del proyecto. Esta fuente deberá

contar con una salida de voltaje adecuada de 5V y 3.3V, y una capacidad de corriente igual o

superior al consumo máximo estimado, para garantizar el correcto funcionamiento del sistema en

todo momento.

Proto. De un Sis. Clasificador de botellas de vidrio en base a su color | 50
V. RESULTADOS
A. Resultados
- El sistema fue capaz de detectar la presencia de un objeto, identificar su color (rojo, verde

o azul) y clasificarlo automáticamente mediante el movimiento del brazo robótico hacia el

compartimiento correspondiente.

- En condiciones óptimas de iluminación, se obtuvo una precisión de clasificación del 85%,

mientras que en condiciones de baja luz, esta bajó al 70%, evidenciando la sensibilidad del

sensor al entorno lumínico.

- La estructura del prototipo se mantuvo estable durante el funcionamiento, gracias al uso de

materiales adecuados y un diseño mecánico correcto.

- El brazo robótico cumplió con las trayectorias planificadas, aunque se observó una

limitación en el alcance angular, ya que el movimiento de la base solo cubre un rango de 0

a 180°, restringiendo el área de trabajo del efector final.

- Durante la fase de pruebas, se identificaron algunos inconvenientes menores relacionados

con la calibración del sensor de color y el control del servomotor. Sin embargo, estos fueron

corregidos rápidamente aplicando el filtrado de señales. El sistema demostró un desempeño

aceptable, cumpliendo con los estándares básicos definidos al inicio del proyecto (detección

y separación de botellas por color).

- Se realizaron pruebas de estrés del sistema, evaluando la precisión en la clasificación de

botellas en distintas condiciones de iluminación y velocidad de la cinta. El rendimiento

alcanzó una efectividad del 85% en condiciones óptimas y del 70% en condicio nes de

iluminación baja, lo cual permitió hacer ajustes en el posicionamiento del sensor.

B. Conclusiones
- Se comprobó que la automatización del proceso de clasificación no solo reduce el tiempo

requerido por operador, sino que también disminuye el riesgo de accidentes laborales, lo

cual contribuye a un entorno de trabajo más seguro.

- Se concluyó que las aplicaciones de simulaciones ayudan mucho al desarrollo del proyecto,

esto viendo, previniendo errores a futuro, y al mismo tiempo modelando las piezas para

poder construirlas al final.

Proto. De un Sis. Clasificador de botellas de vidrio en base a su color | 51
- A pesar del éxito del prototipo, se identificaron áreas de mejora importantes, especialmente

en la estabilidad del reconocimiento de color y la ampliación del rango de trabajo del brazo.

C. Recomendaciones
- Si bien el sensor TCS3200 cumple su función, su precisión se ve afectada en condiciones

de baja iluminación. Se recomienda implementar un sistema de calibración automática o

utilizar sensores más avanzados con filtros integrados para mejorar la exactitud d el

reconocimiento cromático.

- El sistema debería contar con protección ante factores externos como humedad, polvo o

vibraciones. Para esto, se sugiere diseñar una carcasa protectora o encapsular los sensores

más delicados.

- Diseñar una carcasa protectora para los componentes electrónicos, especialmente sensores

y microcontroladores, con el fin de evitar fallas por humedad, polvo o impactos.

- Incorporar una memoria SD o conexión a una base de datos permitiría registrar el número

de botellas clasificadas por tipo, errores detectados y eficiencia general. Esta información

sería útil para análisis posteriores o validación industrial.

Proto. De un Sis. Clasificador de botellas de vidrio en base a su color | 52
VI. | REFERENCIAS
[1] O. D. Valzco, Diseño y Construccion de Estacion de Clasificacion Autoamtica,

Casuca - Colombia: Machine Vision, 2013.

[2] M. F. M. Pérez, Etapa de identificación y clasificación de botellas de PET, en

máquina prototipo separador de botellas, Mexico, 2020 .

[3] L. A. L. López, Sistema mecatrónico de banda transportadora usando impresión

3D para la emulación de procesos industriales, Colombia-Cali, 2022.

[4] | N. | N. | J. | ISMAEL, | AUTOMATIZACIÓN | DE | UNA | CINTA

TRANSPORTADORA PARA LA SEPARACION DE RESIDUOS RECICLABES SEGUN PESO O TAMAÑO, BOLIVIA - Cochabamba, 2024.

Proto. De un Sis. Clasificador de botellas de vidrio en base a su color | a

ANEXOS

Miro

https://miro.com/welcomeonboard/d0VZcmZudFMzZWpQcWEzdktvRURLLyt3S0JqNm

h0eW42eG4rVFZpNjY4WE45VXlob2RSbkg0ZnJvMUZ0WkZwZ1l1a0p6cnJ4ZUxXSEQzOUc

yZ0hEZEpRdkh0ZFRiOXVka1VaZ0I4dDF0Zm1ydXA1WXZ1WS92SnQ2WW1uN2k1aTBnbH

pza3F6REdEcmNpNEFOMmJXWXBBPT0hdjE=?share_link_id=140537677327 (https://miro.com/welcomeonboard/d0VZcmZudFMzZWpQcWEzdktvRURLLyt3S0JqNmh0eW42eG4rVFZpNjY4WE45VXlob2RSbkg0ZnJvMUZ0WkZwZ1l1a0p6cnJ4ZUxXSEQzOUcyZ0hEZEpRdkh0ZFRiOX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)

Formulario

https://forms.gle/agBcHq2ziUJrA7fN7

Drive

https://drive.google.com/drive/folders/1f7mmO3LOPDSBSi_uL6BorWe6adDavS6_?usp

=sharing (https://drive.google.com/drive/folders/1f7mmO3LOPDSBSi_uL6BorWe6adDavS6_?usp=sharing)

Excel

Avances de Proyecto.xlsx

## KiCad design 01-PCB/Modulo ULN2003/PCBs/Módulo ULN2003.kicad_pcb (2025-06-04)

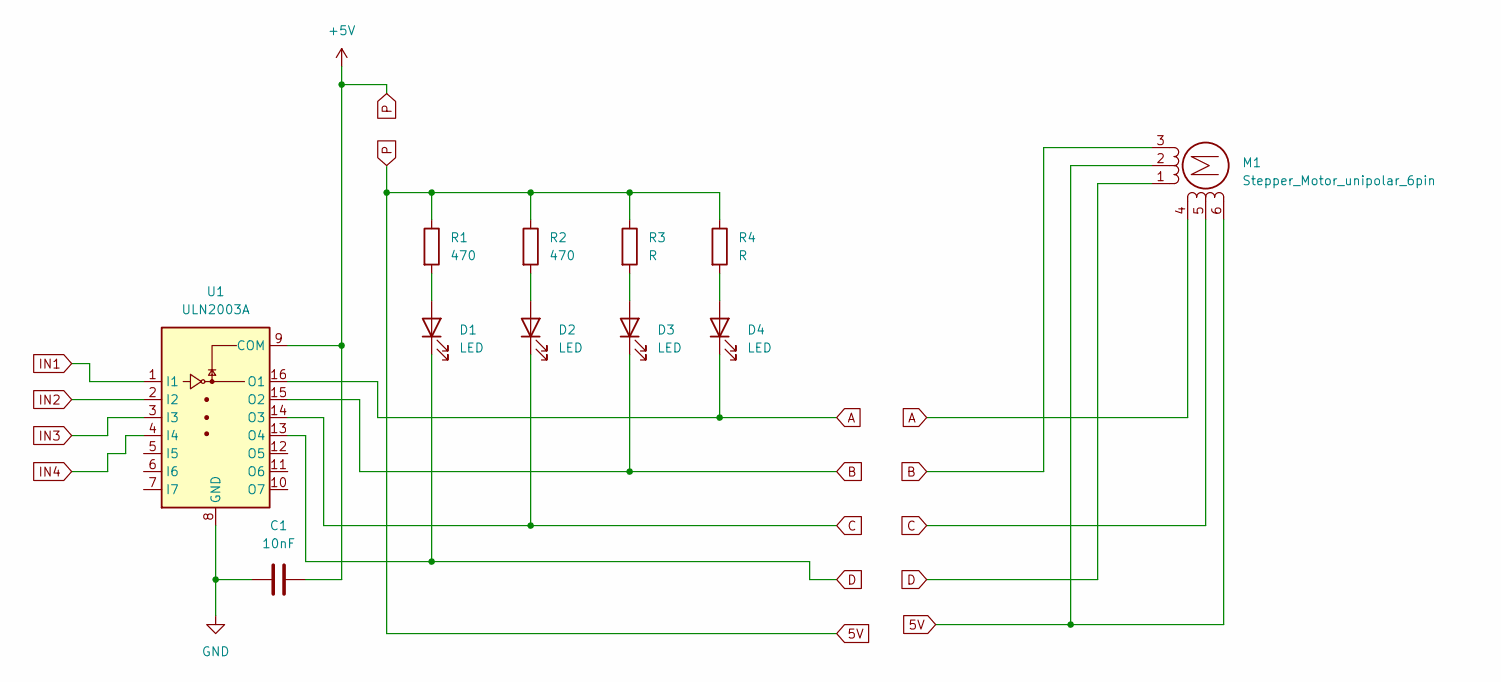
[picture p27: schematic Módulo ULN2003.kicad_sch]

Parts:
C1: 10nF; C_0402_1005Metric
D1, D2, D3, D4: LED; LED_D3.0mm
M1: Stepper_Motor_unipolar_6pin; PinSocket_1x06_P1.00mm_Vertical
R1, R2: 470; R_0402_1005Metric
R3, R4: R; R_0402_1005Metric
U1: ULN2003A; DIP-16_W7.62mm

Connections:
5V: C1.2, M1.2, M1.6, R1.1, R2.1, R3.1, R4.1, U1.9 (COM)
A: D4.1 (K), M1.4, U1.16 (O1)
B: D3.1 (K), M1.3 (-), U1.15 (O2)
C: D2.1 (K), M1.5, U1.14 (O3)
D: D1.1 (K), M1.1, U1.13 (O4)
GND: C1.1, U1.8 (GND)
IN1: U1.1 (I1)
IN2: U1.2 (I2)
IN3: U1.3 (I3)
IN4: U1.4 (I4)
unnamed: D1.2 (A), R1.2
unnamed: D2.2 (A), R2.2
unnamed: D3.2 (A), R3.2
unnamed: D4.2 (A), R4.2

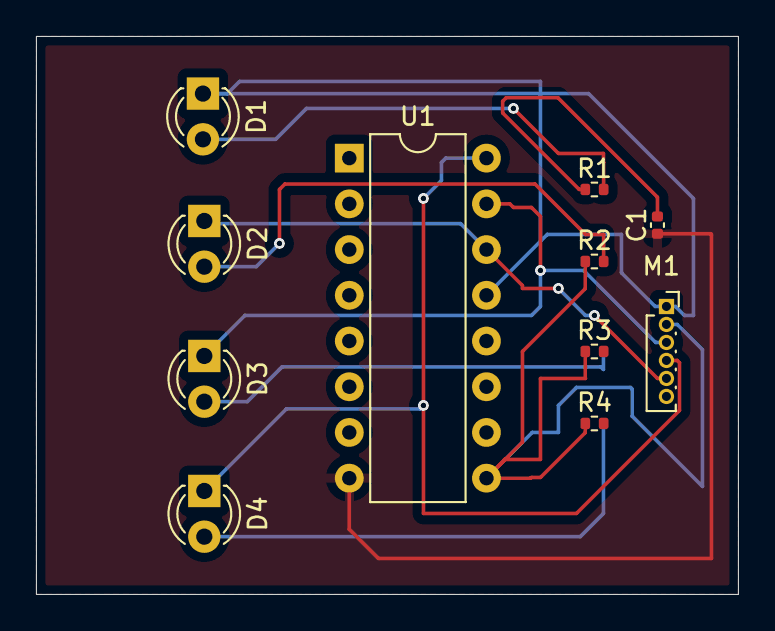
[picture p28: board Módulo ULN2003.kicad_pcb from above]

Board: 2 copper layers, 39.0 x 31.0 mm, 11 parts (0 on the bottom side), 10 nets.

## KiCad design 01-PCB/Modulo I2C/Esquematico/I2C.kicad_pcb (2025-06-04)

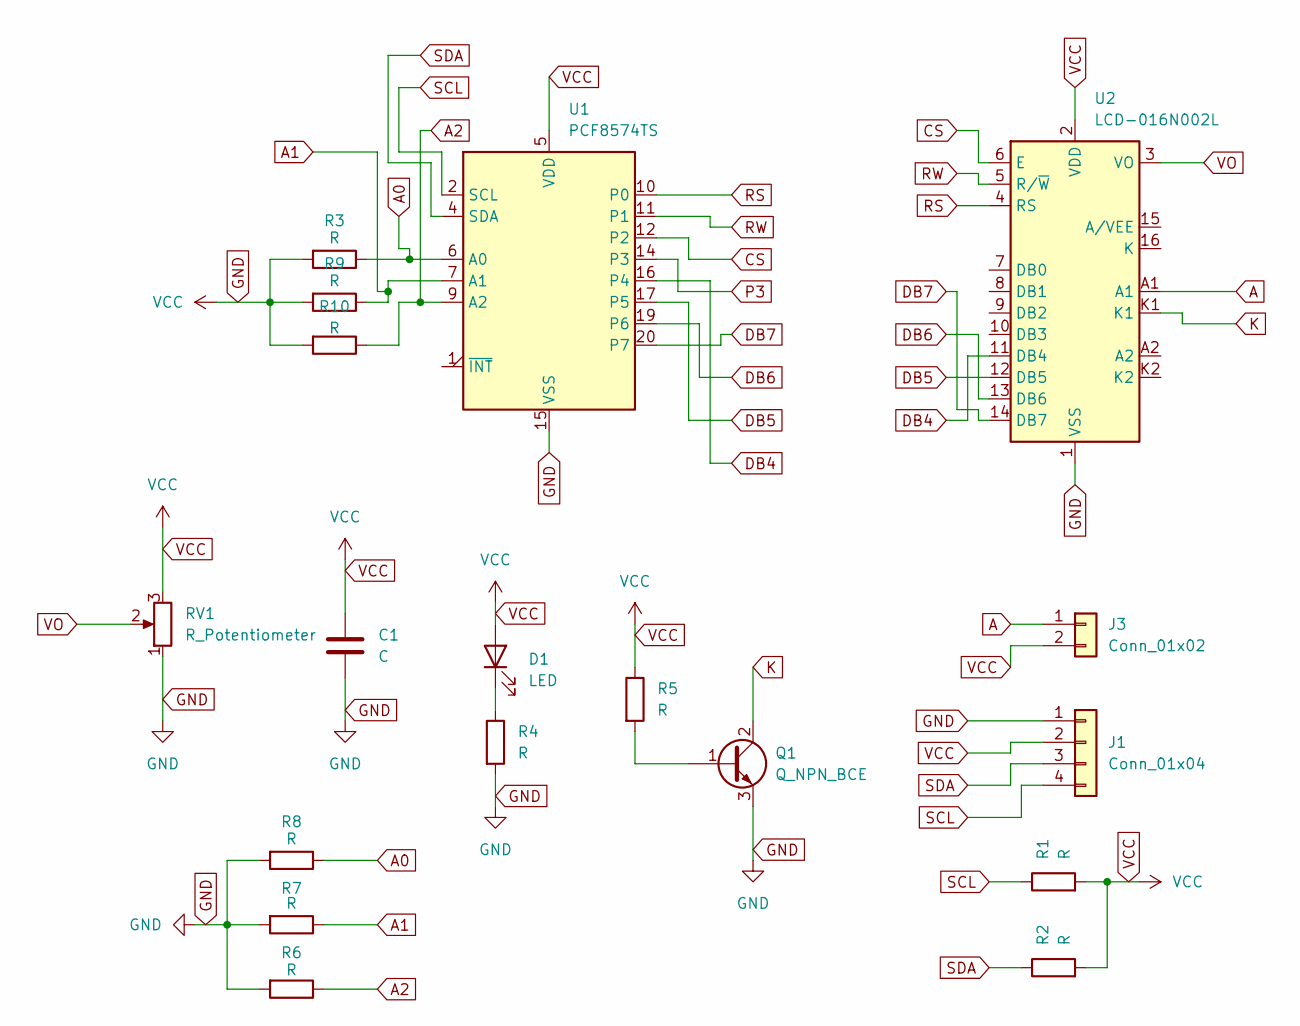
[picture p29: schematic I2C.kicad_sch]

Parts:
C1: C; C_0402_1005Metric
D1: LED; LED_D5.0mm_Horizontal_O1.27mm_Z3.0mm
J1: Conn_01x04; PhoenixContact_GMSTBA_2,5_4-G-7,62_1x04_P7.62mm_Horizontal
J3: Conn_01x02; PhoenixContact_GMSTBA_2,5_2-G_1x02_P7.50mm_Horizontal
Q1: Q_NPN_BCE; TO-92
R1, R2, R3, R4, R5, R6, R7, R8, R9, R10: R; R_0402_1005Metric
RV1: R_Potentiometer; Potentiometer_Bourns_3339H_Vertical
U1: PCF8574TS; SSOP-20_4.4x6.5mm_P0.65mm
U2: LCD-016N002L

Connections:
A: J3.1, U2.A1
A0: R3.1, R8.1, U1.6 (A0)
A1: R7.1, R9.1, U1.7 (A1)
A2: R6.1, R10.1, U1.9 (A2)
CS: U1.12 (P2), U2.6 (E)
DB4: U1.16 (P4), U2.11 (DB4)
DB5: U1.17 (P5), U2.12 (DB5)
DB6: U1.19 (P6), U2.13 (DB6)
DB7: U1.20 (P7), U2.14 (DB7)
GND: C1.1, C1.2, D1.2 (A), J1.1, J1.2, J3.2, Q1.3 (E), R1.2, R2.2, R3.2, R4.2, R5.1, R6.2, R7.2, R8.2, R9.2, R10.2, RV1.1, RV1.3, U1.5 (VDD), U1.15 (VSS), U2.1 (VSS), U2.2 (VDD)
K: Q1.2 (C), U2.K1
unnamed: D1.1 (K), R4.1
unnamed: Q1.1 (B), R5.2
P3: U1.14 (P3)
RS: U1.10 (P0), U2.4 (RS)
RW: U1.11 (P1), U2.5 (R/~W)
SCL: J1.4, R1.1, U1.2 (SCL)
SDA: J1.3, R2.1, U1.4 (SDA)
VO: RV1.2, U2.3 (VO)

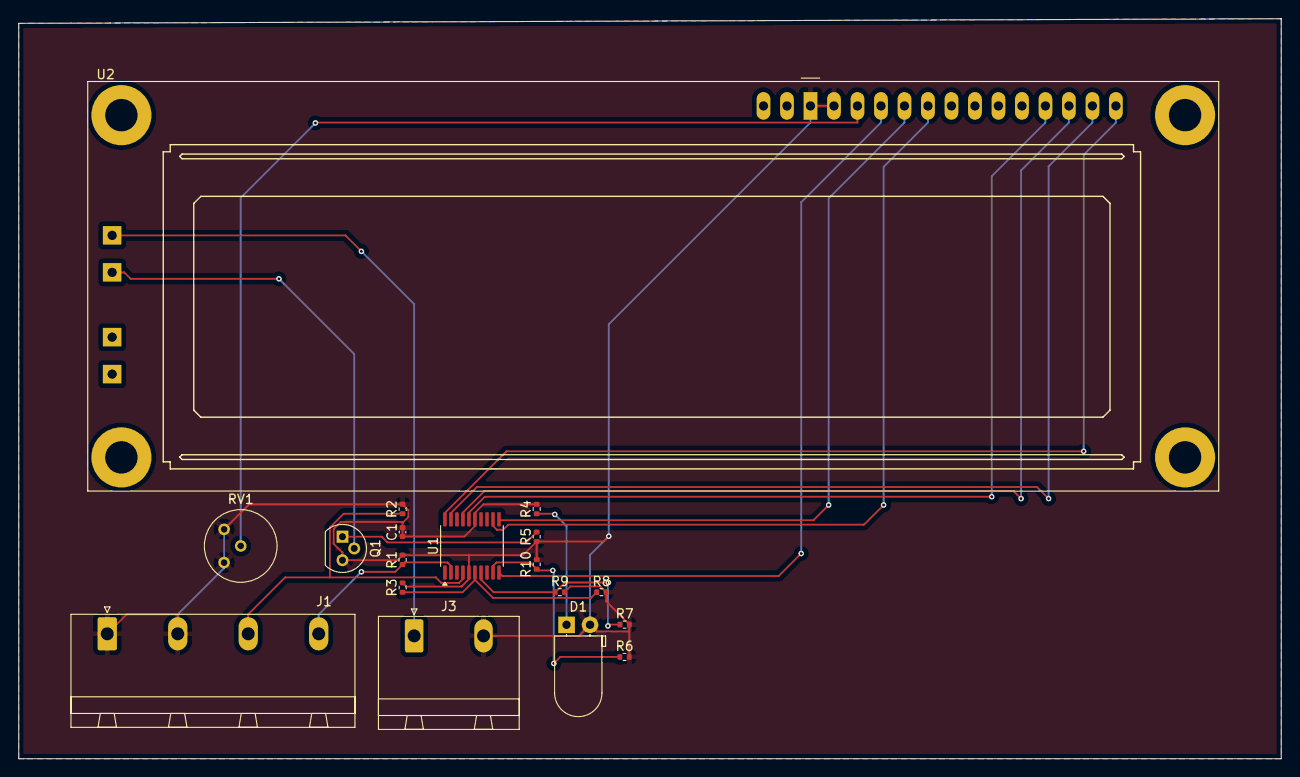
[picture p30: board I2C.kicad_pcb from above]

Board: 2 copper layers, 136.5 x 80.0 mm, 18 parts (0 on the bottom side), 18 nets.

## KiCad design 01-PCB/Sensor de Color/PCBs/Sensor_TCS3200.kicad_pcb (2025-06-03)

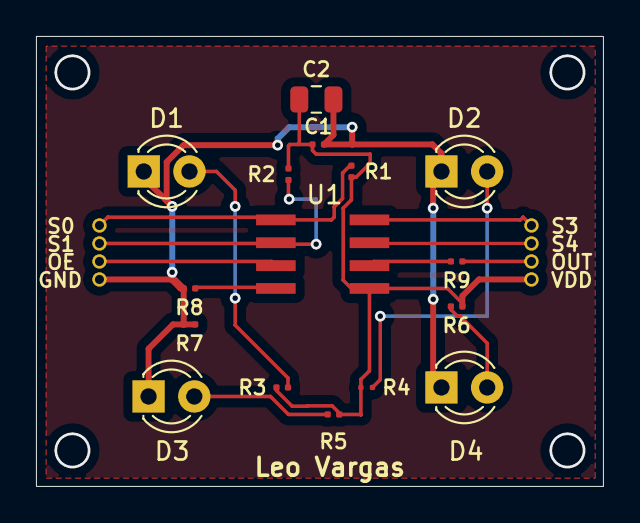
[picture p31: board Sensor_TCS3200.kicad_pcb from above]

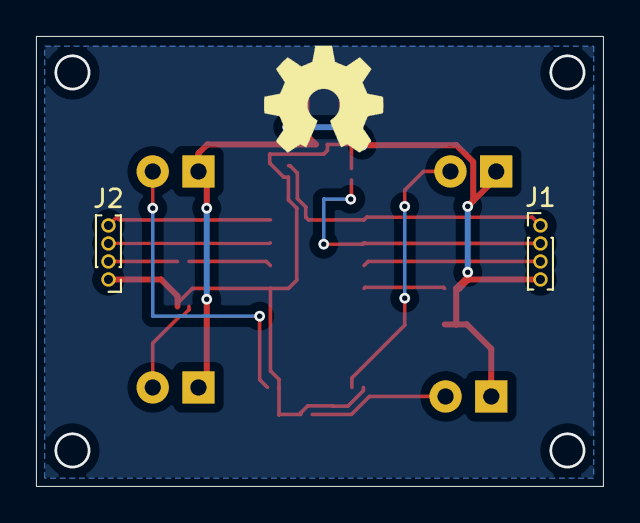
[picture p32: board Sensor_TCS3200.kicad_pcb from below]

Board: 2 copper layers, 31.5 x 25.0 mm, 18 parts (2 on the bottom side), 14 nets.

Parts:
C1: 100nF; C_0201_0603Metric
C2: 10uF; C_0805_2012Metric
D1, D2, D3, D4: D; LED_D3.0mm_Clear
J1, J2: Conn_01x04_Pin; PinHeader_1x04_P1.00mm_Vertical
R1, R2: 10k; R_0201_0603Metric
R3, R4, R5, R6: 330; R_0201_0603Metric
R7, R8: 0; R_0201_0603Metric
R9: 1k; R_0201_0603Metric
U1: TCS3200D; SOIC8

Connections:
GND: C1.2, C2.2, D1.1 (K), D2.1 (K), D3.1 (K), D4.1 (K), J1.4, R7.1, R7.2, R8.2
unnamed: D1.2 (A), R3.2
unnamed: D2.2 (A), R4.2
unnamed: D3.2 (A), R5.2
unnamed: D4.2 (A), R6.2
unnamed: J1.1, R1.2, U1.1 (S0)
unnamed: J1.2, R2.2, U1.2 (S1)
unnamed: J1.3, U1.3 (OE)
unnamed: C1.1, C2.1, J2.1, R1.1, R2.1, R3.1, R4.1, R5.1, R6.1, U1.5 (VDD)
unnamed: J2.2, R9.1
unnamed: J2.3, U1.7 (S2)
unnamed: J2.4, U1.8 (S3)
unnamed: R8.1, U1.4 (GND)
unnamed: R9.2, U1.6 (OUT)

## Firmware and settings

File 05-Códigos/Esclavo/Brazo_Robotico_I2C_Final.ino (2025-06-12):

#include <ESP32Servo.h>
#include <Wire.h>  // Librería para I2C

// Crear servos
Servo servo1;  // Garra
Servo servo2;  // Muñeca
Servo servo3;  // Codo
Servo servo4;  // Hombro
Servo servo5;  // Base

// Pines
const int pinServo1 = 18;  // Garra
const int pinServo2 = 19;  // Muñeca
const int pinServo3 = 23;  // Codo
const int pinServo4 = 25;  // Hombro
const int pinServo5 = 26;  // Base

// Variables de posición iniciales (reposo)
int pos1 = 60;   // Garra
int pos2 = 140;  // Muñeca
int pos3 = 180;  // Codo
int pos4 = 55;   // Hombro
int pos5 = 85;   // Base

// Variables de control
String comando = "";
volatile bool comandoNuevo = false;
volatile int comandoI2C = -1;
bool procesoTerminado = false;
bool emergencia = false;  // Emergencia activa o no

// Dirección del esclavo I2C
#define SLAVE_ADDRESS 0x08

// Función para mover gradual un servo
void moverServoGradual(Servo& servo, int& posActual, int destino, int paso, int tiempo_ms) {
  destino = constrain(destino, 0, 180);  // Limitar entre 0° y 180°

  if (posActual < destino) {
    for (int pos = posActual; pos <= destino; pos += paso) {
      if (emergencia) return;  // Salir si hay emergencia
      servo.write(pos);
      delay(tiempo_ms);
    }
  } else {
    for (int pos = posActual; pos >= destino; pos -= paso) {
      if (emergencia) return;  // Salir si hay emergencia
      servo.write(pos);
      delay(tiempo_ms);
    }
  }
  posActual = destino;  // Actualizar posición final
}

// Función para mover dos servos en paralelo
void moverServosParalelo(Servo& servoA, int& posA, int destinoA,
                         Servo& servoB, int& posB, int destinoB,
                         int paso, int tiempo_ms) {
  destinoA = constrain(destinoA, 0, 180);
  destinoB = constrain(destinoB, 0, 180);

  while ((posA != destinoA || posB != destinoB) && !emergencia) {
    if (posA < destinoA) posA += paso;
    else if (posA > destinoA) posA -= paso;
    posA = constrain(posA, 0, 180);
    servoA.write(posA);

    if (posB < destinoB) posB += paso;
    else if (posB > destinoB) posB -= paso;
    posB = constrain(posB, 0, 180);
    servoB.write(posB);

    delay(tiempo_ms);
  }
}

// Inicializar servos
void setupServos() {
  servo1.attach(pinServo1);  // Garra
  servo2.attach(pinServo2);  // Muñeca
  servo3.attach(pinServo3);  // Codo
  servo4.attach(pinServo4);  // Hombro
  servo5.attach(pinServo5);  // Base

  reposo();
}

// Función reposo: llevar brazo a posición inicial
void reposo() {
  moverServosParalelo(servo4, pos4, 55, servo3, pos3, 180, 1, 10);  // Hombro y codo
  moverServosParalelo(servo1, pos1, 60, servo2, pos2, 140, 1, 15);  // Garra y muñeca
  moverServoGradual(servo5, pos5, 85, 1, 10);                       // Base
}

// Simulación recoger botella
void recogerBotella() {
  moverServosParalelo(servo2, pos2, 120, servo1, pos1, 0, 1, 10);   // Bajar muñeca y abrir garra
  moverServosParalelo(servo4, pos4, 70, servo3, pos3, 135, 1, 10);  // Bajar hombro y codo
  moverServoGradual(servo5, pos5, 172, 1, 10);                      // Girar base
  moverServosParalelo(servo4, pos4, 40, servo3, pos3, 153, 1, 10);  // Subir hombro y codo
  moverServoGradual(servo1, pos1, 40, 1, 10);                       // Cerrar garra
  moverServoGradual(servo4, pos4, 60, 1, 10);                       // Ajustar hombro
}

// Movimiento a contenedor ROJO
void depositarEnRojo() {
  moverServoGradual(servo5, pos5, 70, 1, 10);                      
  moverServosParalelo(servo4, pos4, 5, servo3, pos3, 105, 1, 10);  
  moverServoGradual(servo1, pos1, 0, 1, 20);                       
}

// Movimiento a contenedor AZUL
void depositarEnAzul() {
  moverServoGradual(servo5, pos5, 93, 1, 10);
  moverServosParalelo(servo4, pos4, 5, servo3, pos3, 105, 1, 10);
  moverServoGradual(servo1, pos1, 0, 1, 20);
}

// Movimiento a contenedor VERDE
void depositarEnVerde() {
  moverServoGradual(servo5, pos5, 120, 1, 10);                     
  moverServosParalelo(servo4, pos4, 5, servo3, pos3, 105, 1, 10);  
  moverServoGradual(servo1, pos1, 0, 1, 20);                       
}

// Función que recibe datos I2C
void recibirDato(int byteCount) {
  if (Wire.available()) {
    comandoI2C = Wire.read();  // Leer comando recibido
    comandoNuevo = true;

    //  Si es 3, activar emergencia
    if (comandoI2C == 3) {
      emergencia = true;
      Serial.println("Emergencia activada: Sistema detenido.");
    }
    // Si es 4, desactivar emergencia y regresar a reposo
    if (comandoI2C == 4) {
      emergencia = false;
      Serial.println("Emergencia desactivada: Volviendo a reposo.");
      reposo();
    }
  }
}

// Función para enviar respuesta al maestro
void enviarRespuesta() {
if (procesoTerminado) {
    Wire.write(1); //  Terminado
    procesoTerminado = false;  // Resetear estado
  } else {
    Wire.write(0); // Aún trabajando
  }
}

void setup() {
  Serial.begin(9600);
  setupServos();
  Serial.println("Brazo en reposo. Esperando comandos...");

  Wire.begin(SLAVE_ADDRESS);  // Iniciar I2C como esclavo
  Wire.onReceive(recibirDato);
  Wire.onRequest(enviarRespuesta);

  reposo();  // Posición inicial
}

void loop() {
  if (emergencia) {
    // Sistema en modo emergencia: NO HACER NADA
    return;
  }

  if (comandoNuevo) {
    Serial.print("Comando recibido via I2C: ");
    Serial.println(comandoI2C);

    if (comandoI2C == 0) {
      recogerBotella();
      depositarEnRojo();
    } else if (comandoI2C == 1) {
      recogerBotella();
      depositarEnAzul();
    } else if (comandoI2C == 2) {
      recogerBotella();
      depositarEnVerde();
    } else if (comandoI2C != 3 && comandoI2C != 4) {
      Serial.println("Comando inválido.");
    }

    reposo();                 // Siempre volver a reposo después
    procesoTerminado = true;   // Marcar que terminó
    comandoNuevo = false;      // Resetear bandera
  }
}

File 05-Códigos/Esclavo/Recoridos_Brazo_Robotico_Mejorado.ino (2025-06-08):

#include <ESP32Servo.h>

// Crear servos
Servo servo1;
Servo servo2;
Servo servo3;
Servo servo4;
Servo servo5;

// Pines
const int pinServo1 = 18;
const int pinServo2 = 19;
const int pinServo3 = 23;
const int pinServo4 = 25;
const int pinServo5 = 26;

// Variables de posición iniciales (reposo)
int pos1 = 60;   // Base
int pos2 = 135;  // Hombro
int pos3 = 180;  // Codo
int pos4 = 55;   // Muñeca
int pos5 = 90;   // Garra

String comando = "";

// Función para mover gradual
void moverServoGradual(Servo& servo, int& posActual, int destino, int paso, int tiempo_ms) {
  destino = constrain(destino, 0, 180);  // limitar entre 0-180°

  if (posActual < destino) {
    for (int pos = posActual; pos <= destino; pos += paso) {
      servo.write(pos);
      delay(tiempo_ms);
    }
  } else {
    for (int pos = posActual; pos >= destino; pos -= paso) {
      servo.write(pos);
      delay(tiempo_ms);
    }
  }
  posActual = destino;  // Actualizar posición final
}

// Función para mover dos servos en paralelo
void moverServosParalelo(Servo& servoA, int& posA, int destinoA,
                         Servo& servoB, int& posB, int destinoB,
                         int paso, int tiempo_ms) {
  destinoA = constrain(destinoA, 0, 180);  // Limitar entre 0-180°
  destinoB = constrain(destinoB, 0, 180);

  // Mover hasta que ambos lleguen
  while (posA != destinoA || posB != destinoB) {
    // Mover servo A
    if (posA < destinoA) posA += paso;
    else if (posA > destinoA) posA -= paso;
    posA = constrain(posA, 0, 180);  // Asegura límites
    servoA.write(posA);

    // Mover servo B
    if (posB < destinoB) posB += paso;
    else if (posB > destinoB) posB -= paso;
    posB = constrain(posB, 0, 180);
    servoB.write(posB);

    delay(tiempo_ms);
  }
}


// Inicializar servos
void setupServos() {
  servo1.attach(pinServo1);
  servo2.attach(pinServo2);
  servo3.attach(pinServo3);
  servo4.attach(pinServo4);
  servo5.attach(pinServo5);

  reposo();
}

// Función reposo personalizada
void reposo() {
  moverServoGradual(servo1, pos1, 60, 1, 10);
  moverServosParalelo(servo4, pos4, 55, servo3, pos3, 180, 1, 10);
  moverServoGradual(servo2, pos2, 135, 1, 10);
  moverServoGradual(servo5, pos5, 90, 1, 10);
}

// Simulación recoger botella
void recogerBotella() {
  moverServoGradual(servo1, pos1, 0, 5, 20);  // abrir garra
  moverServoGradual(servo2, pos2, 100, 5, 20);
  moverServosParalelo(servo4, pos4, 70, servo3, pos3, 135, 1, 10);
  moverServoGradual(servo5, pos5, 180, 1, 15);
  moverServoGradual(servo2, pos2, 115, 1, 20);
  moverServosParalelo(servo4, pos4, 38, servo3, pos3, 150, 1, 10);
  moverServoGradual(servo1, pos1, 40, 1, 20);  // cerrar
  moverServoGradual(servo4, pos4, 60, 1, 20);
}

// Movimiento a contenedor ROJO
void depositarEnRojo() {
  moverServoGradual(servo5, pos5, 125, 1, 10);
  moverServosParalelo(servo4, pos4, 5, servo3, pos3, 100, 1, 10);
  moverServoGradual(servo2, pos2, 110, 1, 20);
  moverServoGradual(servo1, pos1, 0, 1, 20);
}

// Movimiento a contenedor AZUL
void depositarEnAzul() {
  moverServoGradual(servo5, pos5, 100, 1, 10);
  moverServosParalelo(servo4, pos4, 5, servo3, pos3, 100, 1, 10);
  moverServoGradual(servo2, pos2, 110, 1, 20);
  moverServoGradual(servo1, pos1, 0, 1, 20);
}

// Movimiento a contenedor VERDE
void depositarEnVerde() {
  moverServoGradual(servo5, pos5, 75, 1, 10);
  moverServosParalelo(servo4, pos4, 5, servo3, pos3, 100, 1, 10);
  moverServoGradual(servo2, pos2, 110, 1, 20);
  moverServoGradual(servo1, pos1, 0, 1, 20);
}

void setup() {
  Serial.begin(9600);
  setupServos();
  Serial.println("Brazo en reposo. Comandos:");
  Serial.println("R = ROJO");
  Serial.println("A = AZUL");
  Serial.println("V = VERDE");
  Serial.println("B = Recoger botella");
  Serial.println("I = Ir a Reposo");
}

void loop() {
  if (Serial.available()) {
    comando = Serial.readStringUntil('\n');
    comando.trim();  // Limpiar

    Serial.print("Comando recibido: ");
    Serial.println(comando);

    if (comando == "R") {
      recogerBotella();
      depositarEnRojo();
    } else if (comando == "A") {
      recogerBotella();
      depositarEnAzul();
    } else if (comando == "V") {
      recogerBotella();
      depositarEnVerde();
    } else if (comando == "B") {
      recogerBotella();
    } else if (comando == "I") {
      reposo();
    } else {
      Serial.println("Comando inválido. Usa R, A, V, B o I.");
    }
    delay(1000);
    reposo();  // Siempre volver al reposo después de la tarea
    reposo();  // Siempre volver al reposo después de la tarea
  }
}

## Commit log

2025-06-03 Acualizacion del la documentacion
2025-06-03 Documentos S.Color
    [Sensor_TCS3200.kicad_pcb]
2025-06-03 Segunda Version de Codigo
2025-06-04 Cambio de Alberto!!!
    [FC-51_Sensor.kicad_pcb, FC-51_Sensor.kicad_sch, I2C.kicad_pcb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]
2025-06-07 Pruevas Varias y ESCLAVO I2C
2025-06-08 Maestro con I2C
2025-06-08 Planos y modelos de cinta
